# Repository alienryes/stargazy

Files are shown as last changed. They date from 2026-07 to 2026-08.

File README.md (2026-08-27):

# 🌌 Stargazy

A stargazing conditions display for the [Raspberry Pi Touch Display 2](https://www.raspberrypi.com/documentation/accessories/touch-display-2.html). It fetches live [AstroWeather](https://github.com/mawinkler/astroweather) forecast data (on the Pi itself, or from Home Assistant if available) and renders an overnight forecast over a live, data-reactive animated night sky, with no interaction required.

Rendered with Pillow and written straight to the Linux framebuffer (`/dev/fb0`) — no X and no display server.

**There are two builds**, sharing one engine. Pick the one that matches the hardware:

| | [`build5/`](build5/) | [`build10/`](build10/) |
|---|---|---|
| Panel | Touch Display 2, **5 inch** | Touch Display 2, **10.1 inch** |
| Board | Pi 4 | **Pi 5 or CM** — four-lane DSI, a Pi 4 cannot drive it |
| Canvas | 1280×720 landscape, rotated to the panel | 1200×1920 portrait, no rotation |
| Pages | Conditions, targets | Conditions, targets, plus conditional pages for **meteor showers**, **aurora**, **satellite passes** and **the Sun** |
| Status | **Proven in service** | **In service** |

Everything that is not layout (both weather sources, the target reports, the imagery, the animated sky, night mode, touch, the framebuffer) lives in [`core/`](core/) and is shared. The rest of this README describes the 5 inch build unless it says otherwise; substitute `build10/` for `build5/` in the commands to install the other one.

**Highlights**

- Tonight's deep-sky verdict (EXCELLENT → NONE) spelled out in bold display type
- Condition bars: cloudless %, seeing, transparency, calm. A reading below its warning mark is drawn hollow instead of filled. **Cloudless is the inverse of obscuration, not of raw cloud cover**: a sky fully covered by thin cirrus is largely observable and is reported that way
- **A real image of the Moon** for the current hour (true phase, libration and terminator) with constellation and next new/full moon dates
- **A lunar eclipse takes over the moon card** for the day before it starts, with the times clipped to the Moon's own rise and set so the panel cannot name a phase that happens after moonset, and **Earth's shadow drawn across the lunar frame at the real geometry** while it runs
- Footer grouped by type — astronomical (moon dates, dusk/dawn) on the right under the moon; meteorological (lifted index, weather) on the left
- Handles the no-astronomical-darkness case for midsummer at high latitudes
- **Live animated night sky** behind the dashboard: **the actual stars overhead**, plotted from a catalogue at their real positions for the configured location and the moment, plus drifting clouds and meteors from tonight's active showers — all **reactive to the actual conditions**
- **Touch controls** hidden until the screen is tapped: night mode, page rotation, paging through the full deep-sky list, brightness and a true blank that drops the display to 0% CPU

---

## 📸 Display layout

### The 5 inch build

Two pages rotate over the same continuous animated sky. Both shots are real frames from the panel's own Pi 4, rendered from live data:

**Page 1 — tonight's conditions**

![The conditions page: a large GOOD verdict in pale blue-white, four labelled condition bars with percentages, and a photographic waning crescent Moon captioned Waning Crescent in Cancer. Each bar is filled to its value inside a hollow outline, so Seeing at just over half sits visibly short of the other three, which are nearly full. A footer gives tomorrow's forecast, lifted index, temperature, dew point, humidity and wind. A meteor is crossing the sky behind the dashboard.](screenshots/conditions.png)

> **Dusk / Dawn** is used in that footer, not sunrise/sunset: AstroWeather's sun rise/set entities report **civil twilight** bounds (sun 6° below the horizon), ~40 min off the geometric sun crossing. True darkness is tracked separately (`astronomical_night_duration`) and drives the "NO DARK SKY" state.

**Page 2 — tonight's targets**

![The 5 inch targets page: a dusk-to-dawn timeline with the astronomical dark window highlighted; an altitude-versus-bearing plot of the planets, with a line beneath it naming the bodies still below the horizon and the times they rise; and four deep-sky cards headed with the range on show out of a much longer list, each card carrying a real sky photograph, object type, constellation, peak altitude and a bar for the share of the dark hours the object stays up.](screenshots/targets.png)

The page-2 timeline only appears once UpTonight has run, and the page leaves the rotation entirely if it has produced nothing, so an empty page is never shown.

A page that has nothing to show leaves quietly, since that is the ordinary case and a warning would sit on the panel on a perfectly good night. A page whose data source actually **failed** is named instead: the conditions page lists it as unavailable for that refresh, so a silent gap and a broken feed do not look alike. This matters most on the 10.1 inch build, where five conditional pages draw on separate feeds.

**Night mode — the same page after dark**

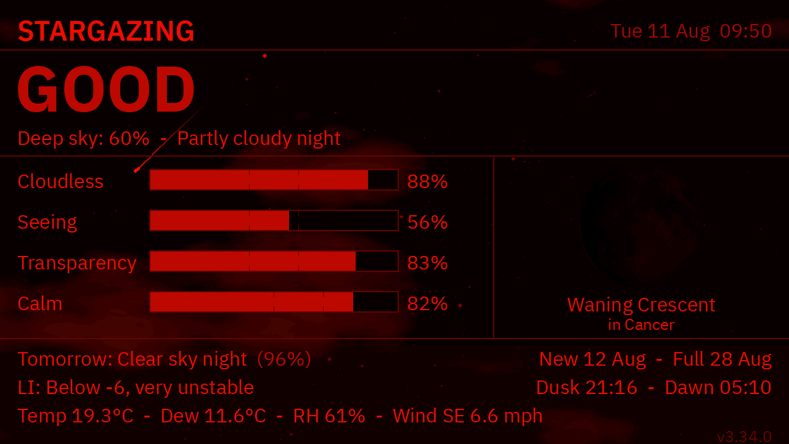
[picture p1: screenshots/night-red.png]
The conditions page in red night mode: the identical layout rendered entirely in shades of red on black, including the photograph of the Moon. The verdict, the condition bars, the percentages and the footer are all still legible, and the bars that fall below their warning marks still read as hollow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


Between real dusk and dawn (not on a clock schedule) the finished frame is put through a red filter, because long wavelengths don't disrupt dark-adapted vision. The whole frame is filtered rather than the palette swapped, which keeps the lunar photograph and the deep-sky cutouts from glowing white.

Because none of the states on the display are encoded by hue, no information is lost. The main verdict is a word, every bar has a number and a length, and a reading below its threshold is hollow rather than a different colour. `night_mode = "dim"` keeps full colour at reduced brightness instead.

### Colour marks real objects; state is neutral

If something on the display is coloured it is a thing that is actually up there — the Moon, a planet, a comet, a photograph of a nebula. If it is a judgement about tonight it is the same neutral blue-white as everything else.

### The 10.1 inch build

Orientation is portrait, 2.5× the pixels at slightly lower density, so the space is used for extra content rather than for scaling. These are real frames captured from the panel's own framebuffer, in service:

**Page 1 — conditions.** The Moon takes the middle band at 600px across; the source frame is 730px, so this is close to native rather than an enlargement. Under it are the numbers that come with the frame and are not used for the 5 inch display — age, distance, apparent diameter, and libration as the direction the near side is tipped.

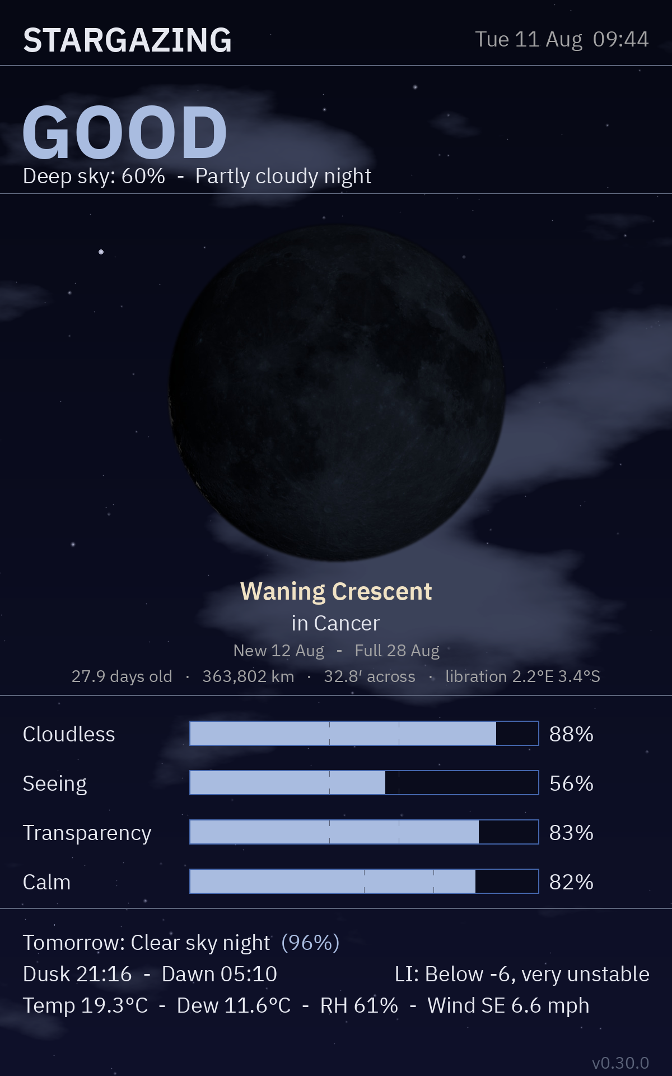
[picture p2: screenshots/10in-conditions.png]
The 10.1 inch conditions page in portrait: a large GOOD verdict, a 600-pixel photograph of a waning crescent Moon captioned Waning Crescent in Cancer with its age, distance, diameter and libration, four condition bars, and a footer of forecast, dusk and dawn times and weather.


**Page 2 — targets.** One altitude-versus-bearing plot carries the planets *and* the deep-sky objects on a full 0–90° axis. The 5 inch build keeps the two apart because it has far less vertical room: UpTonight selects deep-sky targets for high altitude, while the planets stay near the ecliptic and so occupy a lower band, and a short axis holding both compresses whichever band is lower. How far apart those bands sit depends on latitude — from the reference location at 51°N the objects peak around 70–85° and the planets stay below about 35°, but nearer the equator, the ecliptic rides much higher and the two overlap. Every position on the plot is for the single instant named above it.

![The 10.1 inch targets page: a dusk-to-dawn timeline; an altitude-versus-bearing plot carrying the planets alongside the same deep-sky objects as the cards below, each labelled with its bearing; a line naming the bodies still below the horizon with the times they rise; and six deep-sky cards headed with the range on show out of a much longer list, each with a real sky photograph, object type, constellation, peak altitude and where it stands at the plotted instant.](screenshots/10in-targets.png)

**Page 3 — meteors.** Which showers are actually running, from a table of orbital constants indexed by solar longitude, with the rate an observer would count once radiant altitude, cloud and moonlight are accounted for.

A shower is named until its zenithal hourly rate falls to a quarter of the sporadic background's; that background is shown at the foot of the page. Past that threshold it drops off, even though its activity window has not closed; a named row implies something to watch for and when a shower is at a fraction of the background rate it doesn't qualify any more. The windows vary twentyfold in how long they run past maximum, so the cut is made against the rate rather than a number of days. The comparison is made in ZHR rather than in the rates printed on the page, so it does not move with the site's latitude, the radiant's altitude tonight, or the weather. When nothing clears the floor the page leaves the rotation entirely.

The printed rates carry a decimal place below 1/hr. Most nights sit in low single digits and cloud divides them again, so whole numbers at that end of the range have two values and one of them is zero — which would have a named shower reporting that nothing was falling, directly above a sporadic background it is a third of.

![The 10.1 inch meteor page: a header giving the instant the rates are computed for and the current solar longitude, then a row per running shower with its days before or past peak, the radiant's altitude and bearing, a bar and a figure for the rate an observer would count, and its zenithal hourly rate at maximum. Below them a Coming Up list of forthcoming shower peaks with the days to each, and a footer giving the sporadic background rate. Meteors are falling in the sky behind the text, drawn as tapering streaks brightest at the leading end.](screenshots/10in-meteors.png)

---

## ✨ The animated sky

The sky is a live layer composited behind the dashboard each frame (12 fps on a Pi 4 - see the note under Running); the dashboard itself is an RGBA overlay (transparent where the sky should show, opaque content on top). The animation **reflects the conditions** rather than just decorating:

| Condition | Effect |
|---|---|
| Seeing / transparency / calm | Star brightness and twinkle (crisper when clear) |
| Cloud **obscuration** | Fraction of the sky the cloud field obscures, and the stars behind it go out. Derived from the forecast's high/medium/low split rather than its raw cloud fraction. 100% thin cirrus stops far less starlight than 100% stratus, and the raw figure counts them the same. Layers combine as independent transmittances, weighted by `cloudcover_*_weakening`. Falls back to raw cover where the per-layer figures are unavailable |
| Wind speed | How fast the cloud drifts, derived from the wind and a nominal 1500 m cloud base and then time-compressed (`CLOUD_COMPRESSION`, default 8). The honest rate is far too slow to read as motion. Stated as degrees of sky per second, so both panels show the same weather at the same apparent speed despite their different angular scales |
| No astronomical darkness | Sky washes to twilight blue; meteors suppressed |

The moon card shows **a real image of the Moon** (set `display.moon_ring = true` to outline the full disc), fetched hourly from NASA SVS's Dial-a-Moon and cached on disk. It uses actual phase, libration and terminator rather than a drawn approximation. If the API can't be reached the display falls back to drawing the phase geometrically, so it degrades rather than breaks. It deliberately does not reuse an older cached frame: the phase moves about 12° a day, so yesterday's picture would be incorrect, and the correct drawing is better than an attractive but wrong photograph.

**A lunar eclipse replaces those captions** for the 24 hours before it begins, on both builds: the kind of eclipse, the window it can be watched in, and how much of the Moon's diameter enters the umbra. The 10.1 inch build has the room for two further lines and adds the date and an observing note.

**The times are clipped to the Moon's own rise and set, and that is the part that depends on the site.** A lunar eclipse is visible from a whole hemisphere at once, so "is it visible from here" barely filters anything; what is genuinely local is that the Moon can set partway through. At the partial eclipse of 28 August 2026, seen from 51.4°N, the shadow left the Moon at 06:52 with the Moon already below the horizon (it set at 06:24, still deep in the umbra). The card gives the window as ending at moonset and says how much of the eclipse that costs, rather than printing a last contact for something that has gone.

**Earth's shadow is drawn over the lunar frame while the eclipse is running**, because the frame does not carry it: Dial-a-Moon models phase and libration but not eclipses, and reports an obscuration of zero at the maximum of this one. Without the overlay the card would show an ordinary full Moon directly above a caption announcing an eclipse.

**The geometry is computed; the colour is representative.** The shadow's size, position and the curvature of its edge against the limb are real — the umbra is about 2.7 lunar radii across, and it is scaled by the same factor as the disc, so the relation between the two is exact even though the disc itself is drawn far larger than the Moon's true angular size. What is not physical is the brightness: a real umbra is thousands of times fainter than the full Moon, which on a panel in a lit room would simply read as absent, so the shadowed part is drawn as a dim copper (the colour comes from sunlight refracted through Earth's atmosphere, reddened the way a sunset is). The shading is carried by brightness rather than hue, so it survives red night mode — which is the mode the panel is in whenever an eclipse is worth watching.

**The shadow's position is as fresh as the rest of the page**, which is to say it advances a step at each data refresh rather than continuously.

**Only umbral eclipses appear.** A penumbral eclipse is a faint shading that cannot be separated from an ordinary full Moon by eye, and the penumbral contacts of a partial one are no more visible — announcing them would name a time to go out and look at nothing. This is the same test every conditional page here has to pass.

Like the solar eclipse on the 10.1 inch build's Sun page, **it needs no network**: it is computed locally and cached until the event has passed, so it still announces itself with the internet down.

Star and cloud brightness always keep a visible floor, so the sky stays alive even on poor nights.

**The clouds pass behind the moon card, and that is deliberate.** The disc on the dashboard is a *card*, not a view through a window; it is drawn about fifty times the Moon's true angular size (the sky layer runs roughly 21 pixels per degree on the 10.1 inch panel, where the real Moon would be about 11 pixels across) and it sits at a fixed place in the layout rather than where the Moon actually is. Letting cloud drift across it would suggest that the Moon really is there, that large, in that direction. The dashboard describes the sky; only the layer behind it depicts the sky. The Moon's true position is on the targets page, on the alt-az plot with the other potential targets for the night.

### The starfield is the real sky

The stars behind the dashboard are not decoration. They are plotted from the Yale Bright Star Catalogue at their true altitude and azimuth for the configured location and the current moment, recomputed every minute, and they drift in line with the Earth's spin.

**Constellations are recognisable**. This was checked on the panel; on 11 August 2026 at 09:30 the 10.1 inch build had all seven of Orion's main stars in frame, Betelgeuse within two degrees of the view centre, and the belt read at a glance. This was during daylight: Orion is a morning object in August, so the panel was showing a dark sky that could not have been seen out of the window at the time.

**Only displayed down to a `limiting_magnitude`, default 5.0 — not the catalogue's 6.5.** The catalogue's faint end references stars nobody at the reference location would see: measured over the 5 inch field of view it put 1,204 stars on screen, of which 983 were fainter than magnitude 5 and those carried 56% of the drawn area. They buried the sixteen stars that actually made a pattern, and a real sky came out looking random. Raise it for a genuinely dark site. The catalogue ships in the repository, so this needs no network connectivity.

**The panel does not know which way it is facing, so the direction in which it looks is configuration rather than something inferred:**

```toml
[sky]
real_stars = true
camera_azimuth = 180    # degrees: 0 = north, 90 = east, 180 = south
camera_altitude = 45    # degrees above the horizon at the centre of the view
field_of_view = 70      # degrees, vertical (build10 defaults to 90)
```

The default view faces **due south at 45° up**, which is where objects transit and therefore the most useful direction at northern latitudes. Point it wherever the window actually faces, or wherever the view is best. The horizontal field is derived from the panel's aspect ratio so the scale stays even in both directions — which means the landscape 5 inch build sees considerably more sky than the portrait 10.1 inch one at the same vertical setting.

Brightness and star size are mapped for legibility at a distance rather than photometrically: the ordering is faithful, so Sirius still dominates, but the range is compressed; a sky spanning eight magnitudes is drawn across about 1.5, with size carrying the rest. Each panel has its own size table, because the 10.1 inch shows a narrower window of sky magnified over 2.5× the pixels. Set `real_stars = false` for a pseudo-random starfield.

### The meteors follow tonight's real showers

**They are representations, not observations.** A meteor on the panel does not correspond to a meteor in the sky, and nothing on the panel is a live feed. What is real is everything governing their behaviour — when they fall, how often, and which direction they go.

**The cadence** comes from the same computation that fills the 10.1 inch meteor page: which showers are running, how high each radiant sits, and how much of the rate is reduced by cloud and moonlight. So a quiet night in March shows almost nothing and a clear Perseid peak is busy, and if nothing is falling, nothing falls on the display either. The rate is deliberately time-compressed (`meteor_compression`, default 20), because a real three-an-hour would make the animated sky look broken; it does scale what is there but doesn't invent anything.

**The direction** is the true radiant. A meteor is drawn from one of tonight's active showers in proportion to that shower's rate, and travels away from where that shower's radiant actually is in the projected sky, so it converges on a point that agrees with the stars around it. Trails shorten towards the radiant, since a path pointing at the observer would be seen end-on. The radiant can quite often be off the edge of the panel, as the view faces one direction and the shower is in another, so its meteors sweep in near-parallel from that side. Meteors belonging to no shower (the sporadic background, which is most of them on an ordinary night) use an arbitrary direction, because they genuinely have none. Setting `sky.real_stars = false` sets the meteors to arbitrary directions along with the pseudo-random starfield.

Sources for the animated sky: the Yale Bright Star Catalogue (Hoffleit & Warren, 5th revised edition) via VizieR at CDS Strasbourg for the starfield; NASA SVS's Dial-a-Moon, by Ernie Wright, for the lunar frame; the IMO Working List of Visual Meteor Showers for radiants, peaks and zenithal hourly rates, with the activity falloff from Jenniskens (1994). The catalogue and the shower table ship in the repository; only the lunar frame is fetched.

---

### Aurora, when there is any (10.1 inch build)

This page exists **only when aurora is above the configured location's horizon and it is dark enough to see it**. At temperate latitudes that means it may be absent for years at a time; in Iceland or northern Norway it will be a regular fixture. Both are correct, and the frequency difference is real rather than a setting.

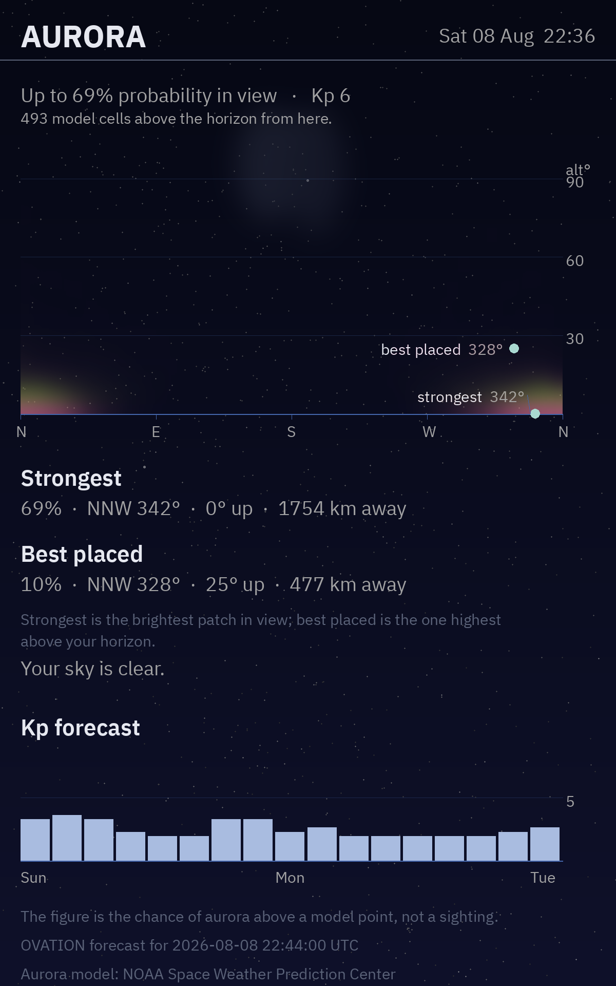
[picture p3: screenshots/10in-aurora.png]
The aurora page during a real storm: 69 percent probability at bearing 342 degrees on the horizon, a second cell 25 degrees up to the north-north-west, a drawn field along the northern horizon shading from yellow-green low down to magenta above, and the three-day Kp forecast.


> **A real storm, 8 August 2026, Kp 6.** The strongest cell was 69% at 1,754 km on the horizon to the north-north-west; the best-placed one 10% at 25° elevation and 477 km. Captured with `--no-night` so the emission-height colours are visible. Between dusk and dawn the panel renders this page in red, which is when it exists. This replaces the injected-storm screenshot the page shipped with, retained as `screenshots/10in-aurora-simulated.png`.

**The query is not "the probability at my latitude".** Aurora emits 100–250 km up, so it is visible far beyond the ground it sits over; from 51°N the horizon reaches past 67°N. Reading only the model cell that contains the configured location can return zero even though a good display is genuinely visible to the north or south. Instead, every model cell within the horizon is searched.

**The direction is not assumed.** The auroral oval passes overhead at high latitudes and lies to the *south* in the southern hemisphere, so the bearing and elevation are computed rather than presumed. The same code answers "north and low" from southern England, "overhead" from Reykjavik and "south" from Tasmania, none of them special-cased.

Two model cells are reported, because they answer different questions and are routinely different: the **strongest**, and the **best placed** — the highest above the horizon. The strongest is often the one grazing the horizon, where the whole thickness of the atmosphere and any terrain at all stand in the way. So reporting that cell alone may send the observer to look at nothing.

**The storm itself is drawn**, not just its extremes: every lit model cell is classified by bearing and elevation and shaded by its probability, so the shape on the plot is the model's own from the observer's position. Opacity *is* the probability (a 60% cell is drawn 60% solid), and the blur only smooths the grid's steps. No structure is added; curtains and rays are not something the model can resolve.

**Colour follows emission height.** The green line is emitted around 100–150 km and the red from 200 km upward, and the Earth hides the lower part first. So the colour is computed from the lowest altitude still above the horizon at each cell's distance. A distant aurora renders red because the red tops are genuinely all that clears the horizon, and one overhead renders green. That is why southern England reports a red glow while Tromsø gets green, and the same code produces both. It is an inference from geometry rather than something OVATION reports, and between dusk and dawn the panel's night mode collapses everything to red luma anyway, so the colour is naturalism and doesn't carry meaning on its own.

The page also carries SWPC's three-day Kp outlook, and says whether the local sky is clear enough to act on any of it. Everything shown is a **probability from a model, roughly 76 minutes ahead of its observation time** — not an observation.

Source: NOAA SWPC's OVATION model. No key, no registration.

---

### Satellite passes (10.1 inch build)

A page that appears **when a bright satellite crosses this sky within the coming day**. Unlike the other conditional pages it is not gated on the sky being dark now, because a pass is an appointment rather than a condition.

![The 10.1 inch satellite page in portrait: a headline naming the next bright pass with its time and how long until it, trailed by a solid line sample keying it to the plot, then a line giving where it rises, how high it climbs and in which direction, and where it sets, and a line giving minutes in view and range at its highest. Below that an altitude-versus-bearing plot on a 0 to 90 degree axis over the compass points, carrying one solid beaded arc for that pass with a round marker part way down its descending limb, and three dashed arcs behind it for the other passes of the same night. Beneath the plot two listings: tonight's passes, each row giving date, time, object, its dash pattern, peak altitude and the bearings it travels between; and the best for the next seven days, whose rows carry no dash sample because they are not plotted. A three-line footer explains the beads, the marker and the faint track, and credits CelesTrak for the elements along with their age. Cloud drifts behind the whole page.](screenshots/10in-satellites.png)

> **A real capture, 18 August 2026**, taken off the panel with the rotation paused on this page. The next pass was still eleven hours away, which is why the page was up in daylight: it is gated on a pass falling within the day, not on the sky being dark now.

**This is the one man-made thing the display will draw into the sky layer.** Everything in that layer claims to be in front of the observer at that bearing and that altitude, and a pass can honour the claim: the object really is there, at that minute. The aurora field and the Moon card are dashboard content precisely because they cannot.

**Visibility is not darkness alone.** The satellite has to be in sunlight while the observer is not, which is why passes belong to twilight rather than the middle of the night, when the object is in the Earth's shadow and there is nothing to see. The gate is civil twilight rather than the astronomical darkness the aurora page waits for, since waiting for full darkness would discard the twilight passes, which are most of the good ones. A pass also has to reach 10° at its highest to be worth announcing, or it spends its whole duration in haze and behind whatever is on the horizon.

**Nothing here predicts a brightness.** Apparent magnitude depends on which face is turned towards the observer, and no keyless source reports the attitude. Range and altitude are given instead, both computed rather than estimated. Which objects are bright enough to qualify at all is CelesTrak's judgement: the page tracks its `visual` group rather than a list kept in this repository, which would decay silently as objects re-enter and new ones launch. Rocket bodies, debris and numbered military payloads are filtered out by name, leaving the named payloads — the two stations, the BlueBirds, and the reliable sun-synchronous set.

**Ranking on height alone was measured to be worse than no ranking.** Across the group a week holds dozens of near-zenith passes, so height saturates and the winner is effectively arbitrary: the page once led with a 1970 ion-engine testbed at three in the morning while an ISS pass the same evening went unmentioned. Objects are sorted into two tiers instead, with height ordering them within a tier.

**The path is why this is a page rather than a line of text.** The headline pass is plotted on the same bearing-by-altitude panorama the other pages use, so the track needs no axes of its own. Beads along it mark minutes, a faint stretch is time spent in the Earth's shadow, and the moving marker shows direction rather than speed. The other passes of the same night are drawn behind it, dimmed, each keyed by its dash pattern to its row in the listing beneath, so an arc and the row describing it cannot disagree. Below the plot are two blocks: tonight's passes, and the best of the next seven days.

The listing reaches a week while the page itself is gated on the coming day, because whether the page exists is a question about acting tonight and the list is a schedule. It stops at a week deliberately: pass times come from orbital elements that age, and quoting a minute a fortnight out would state a precision the elements do not carry. Elements are refreshed twice a day and the display refuses to predict from a set more than three days old, because a stale element set does not produce an obviously wrong answer, it produces a plausible one at the wrong minute. `[satellites] enabled = false` removes the page.

Source: CelesTrak's GP element sets, one grouped request rather than one per object. No key, no registration.

---

### The Sun, while it is up (10.1 inch build)

Every other conditional page here exists only after dark, because aurora and meteors are conditions of the night sky. This page inverts that: it appears **whenever the Sun is above the horizon**, and fills the hours when the rest of the panel has less to say.

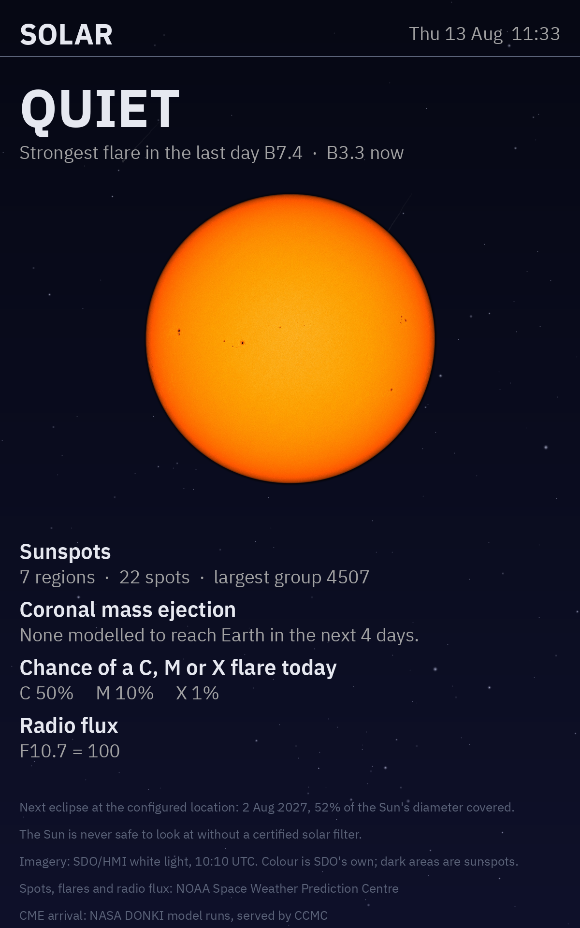
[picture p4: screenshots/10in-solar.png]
The solar page on a quiet day: the word QUIET over the day's strongest flare, rows for sunspots, coronal mass ejections, flare odds and radio flux, and below them a photograph of the Sun's disc in white light with individual sunspots visible as small dark marks.


> **An ordinary quiet day, 13 August 2026** — captured off the panel. Seven spot regions, nothing above a B-class flare, and no CME modelled to arrive.

It is also the only page here that is **always present rather than gated on something happening**. That is a deliberate departure from the rule the other pages follow, because the Sun is always there: a quiet Sun is still a fact about today, not just an empty page.

**The disc is a photograph.** SDO's HMI continuum frame; the white-light view, which is the one with the sunspots actually in it. It is composited the same way the Moon card composites its Dial-a-Moon frame, on the same black field with the same circular mask. The mask is doing real work here: it removes the caption strip SDO prints along the bottom of every frame. What the frame resolves is **individual spots** rather than the groups they belong to: labelling the dark blobs gives 11–21 of them against SWPC's 22 spots in 7 regions on the same day, so the credit names spots and the sunspot row carries both counts. The colour is SDO's own, a table applied to continuum intensity: from space the Sun is white, and the page states that the colour is applied rather than observed. All of that sits in the footnotes as `Imagery: …`, with the other attributions, rather than as a caption under the disc.

The imagery replaced a drawn disc and fixed the issues it brought with it. The drawing plotted each group from SWPC's regional report and overlaying those computed positions on an SDO frame showed **every mark sitting east of its real spot by about the same amount** — because the report is a *daily* snapshot while solar rotation carries a group roughly 13.2° a day, up to 110 px at this scale by the time the next one is issued. The projection was correct; its input was stale, and only a photograph could have shown that. A frame has no such lag: it shows the spots where they were at its own timestamp, which is what the page displays.

The drawn disc survives as the fallback for when SDO cannot be reached — orthographic, tilted by the season (the Sun's axis leans up to 7.25° either way through the year, so the equator bows off centre and the disc reads as a sphere), far-side groups dropped rather than folded onto the wrong limb, and solar west to the right as in every published solar image. In that state the marks are enlarged to be visible and the caption says the positions are as last reported rather than as they are in the present.

**An eclipse gets top billing** when one is due within a day, with a countdown. It is stated as a single line at the foot however far off it is otherwise; the rarest thing this panel shows is worth knowing about in advance. From southern England expect roughly one visible partial a year and none at all in some years; the next is 2 August 2027.

**Magnitude and obscuration are given separately and named separately.** Magnitude is the fraction of the Sun's *diameter* covered, obscuration the fraction of its *area*. They're not the same number: at a deep partial they differ by ten points. The page never prints one under the other's label.

**The eclipse needs no network at all.** It is computed locally from the Sun's and Moon's apparent discs, seen from the configured location so that lunar parallax is included. That makes it the one thing this display can still announce with the internet down.

**Nothing on the page is phrased as an instruction or invitation to look at the Sun without protection**, and the filter warning follows what it qualifies: it sits beside the coverage figures while an eclipse holds the top of the page, and in the footnotes the rest of the time, alongside the next eclipse line.

Sources: NOAA SWPC for spots, flares and radio flux; NASA's DONKI model runs served by CCMC for a coronal mass ejection's predicted arrival and Kp; NASA SDO/HMI for the disc. All keyless, none requiring registration.

## 👆 Touch controls

Since the panel is a touchscreen, there are touch controls. The display reads them directly from `/dev/input/eventN`, so neither X nor Wayland is required.

No controls are drawn until the screen is touched. **The first tap only reveals a control strip** along the bottom, which will disappear after six seconds; a second tap presses a button. That way the ambient display stays uncluttered and brushing past the panel in the dark can't affect anything.

The buttons carry glyphs rather than words, drawn from primitives rather than shipped as an icon font. Each shows what pressing it will **do**, the way a play triangle does — the moon means "press for night", not "it is night".

| Button | Glyph | What it does |
|---|---|---|
| Night / Day | crescent moon / rayed sun | Turns the red night filter on or off, immediately, whatever the hour |
| Pause / Resume | two bars / triangle | Holds the current page instead of rotating |
| Next | chevron | Jumps to the next page straight away |
| Dimmer / Brighter | hollow sun with − / + | Backlight, via `/sys/class/backlight`. Never goes below the lowest visible step |
| Blank | screen with a slash | Backlight off and compositing stopped. The display drops to **0% CPU** until it is touched again. |
| More | three dots | *Targets page only.* Steps to the next screenful of deep-sky objects, and wraps at the end |

The Day sun is **solid** and the brightness suns are **hollow**, which is the same distinction doing real work: both can be on the strip at once, since Day appears whenever the filter is on.

**State is coded in luma, not hue** — fill against outline, solid against hollow — because the night filter puts Rec.709 luma on the red channel and destroys hue outright. A colour code would read correctly by day and collapse into an arbitrary brightness code after dusk, which is the whole time anyone is out there touching the panel.

The moon is the single exception, and it is a provable one. It is drawn only when the filter is off, so it is never transformed, and it is painted in the colour white *becomes* under the filter — the button previews the change it makes. The sun is its mirror, shown only while the filter is on, so it carries no colour and does not try to: at night the whole panel is already red, and previewing "day" would restate what fills the view.

**More** exists because the deep-sky list is far longer than one screenful. UpTonight commonly passes forty objects on a dark night, against six cards on the 10.1 inch panel and four on the 5 inch, and the heading has always said so — `DEEP SKY (1–6 of 40)`. Pressing **More** reaches the rest, six or four at a time; on the 10.1 inch build the altitude-versus-bearing plot follows, so the plot and the cards always describe the same objects.

Every screenful is drawn in advance on the data thread, along with the sky photograph for each object, because stepping between them happens on the render loop where a fetch is too expensive. The page rotation also holds while the control strip is showing, so a page cannot turn mid-press.

A night mode picked by hand lapses the next time the sky crosses dusk or dawn: it is a change of state for that night, not a second schedule competing with the automatic one. Nothing else in the touch controls is persisted. `config.toml` is restored on restart, so the display always comes back to a known state.

This functionality requires `display.mode = "animated"`, and an account in the `input` and `video` groups (`setup.sh` arranges both). Set `touch.enabled = false` to turn the touch controls off.

---

## 🛠️ Requirements

**Hardware** — the whole build, and roughly what it costs:

| Item | Qty | Notes |
|---|---|---|
| Raspberry Pi 4 Model B (2GB is plenty) | 1 | What this is built and proven on. See the Pi 5 note below |
| Raspberry Pi Touch Display 2, **5 inch** | 1 | 720×1280 DSI. Ships with a Pi 4 DSI cable |
| Official Raspberry Pi USB-C PSU (5.1V/3A) | 1 | The printed stand is sized so this one's stiff cable clears the desk |
| microSD card, 16GB+ | 1 | Raspberry Pi OS Lite 64-bit |
| 3D-printed case and stands | 1 set | Optional — see [`case/`](case/README.md). ~150g of PETG |
| M2.5 screws and standoffs | 1 set | Only for the case; full list in [`case/README.md`](case/README.md) |

No soldering, no HAT, no GPIO wiring. The display is DSI and the case is all screws and standoffs. If a 5v GPIO pin is required then the 0 v pin of the display connector can be shifted to the middle pin and the connector moved right by one pin. This frees up Pin 2. Normally the connector connects via Pin 2 and Pin 6, which blocks pin 4.

> **Using a Pi 5 for the 5 inch build gives no advantage.** It needs a Display Adapter Cable for Pi 5 (22-way → 15-way, the one marked `DISPLAY`), and there is no performance reason to move: the render loop is single-threaded and uses about one core of four. The case *does* have a printable Pi 5 variant.
>
> The framebuffer format differs between the two panels and is **detected at runtime**, so neither build needs configuring for it: the 5 inch reports 16bpp RGB565, the 10.1 inch on a Pi 5 reports 32bpp XRGB8888. To see what a board presents:
> ```bash
> cat /sys/class/graphics/fb0/bits_per_pixel /sys/class/graphics/fb0/virtual_size
> ```
> A padded framebuffer (one whose `stride` exceeds width × bytes-per-pixel) is not supported, and is refused at startup rather than rendered as a diagonal smear. Neither panel pads.

**For the 10.1 inch build**, the table changes: a **Raspberry Pi 5** (its DSI is four-lane, which the panel requires), the **10.1 inch** Touch Display 2, a 27W USB-C PSU, and the official **Pi 5 Active Cooler**, which is required rather than optional on a continuous render loop.

**The 10.1 inch build deliberately has no case, and doesn't need one.** The Pi bolts to the standard 58 × 49 mm hole pattern in the middle of the panel's back, which mounts it properly on its own — unlike the 5 inch, where the case and the Pi share one screw chain. Leaving the board open also suits the active cooler, which needs free air rather than a grille. The panel is 247 mm tall in its native portrait with the Pi centred, so there is roughly 80–95 mm below the board for the display ribbon and the power cable to turn and drop; the 5 inch needs a stand partly because rotating it to landscape leaves only about 18 mm there. A stand is still wanted for the 10.1 inch, but that is a question of how it sits on a desk, not of enclosing anything.

**Software**
- Raspberry Pi OS Lite 64-bit (Trixie / Bookworm), headless (`multi-user.target`)
- Python 3.11+
- **No Home Assistant required.** Weather comes from [pyastroweatherio](https://github.com/mawinkler/pyastroweatherio), the library the Home Assistant [AstroWeather](https://github.com/mawinkler/astroweather) integration itself wraps, talking straight to MET Norway and Open-Meteo. If Home Assistant is available with that integration, then set `weather.source = "homeassistant"` and the display reads its sensors instead.
- **An internet connection**, but nothing else on the local network. The 5 inch build uses three public services: the weather above, NASA SVS for the lunar image, and CDS Strasbourg for the deep-sky cutouts. The 10.1 inch build adds four more for its conditional pages: NOAA SWPC for aurora and space weather, NASA's DONKI runs served by CCMC for CME arrival, NASA SDO for the solar disc, and CelesTrak for the satellite elements. All are keyless and none require registration. No broker, no container, no local servers. Each one degrades on its own if it's unreachable. The moon falls back to a drawn phase, the cutouts to drawn glyphs, and cached weather keeps the dashboard up.

---

## 🚀 Setup

### 1. Pi one-time setup

The 5 inch Touch Display 2 is auto-detected over DSI and needs no device-tree overlay. **The 10.1 inch is not**: `display_auto_detect=1` is firmware-side probing, so firmware older than the panel does not recognise it, and the symptom is no output *and* no DSI connector at all in `/sys/class/drm`. For that panel, add the overlay to `/boot/firmware/config.txt` and reboot before running setup:

```
dtoverlay=vc4-kms-dsi-ili79600-10-1inch
```

Append `,dsi0` only if the ribbon is in CAM/DISP 0. The overlay defaults to DSI1, which is CAM/DISP 1. Then run the setup script:

```bash
# Copy the build's setup.sh to the Pi, then:
sudo bash setup.sh          # or: sudo bash setup.sh <username>
sudo reboot                 # required: setup.sh adds fbcon=map:2 to the kernel cmdline
```

With no argument it sets everything up for the account that invoked `sudo`, which is almost always what is required. Pass a username only if installing on behalf of a different account.

`setup.sh`:
- installs `fonts-ibm-plex` (the display's typeface), `fonts-dejavu-core` (fallback), `python3-pil`, `python3-numpy`, `python3-requests`, `python3-pip`, `python3-venv`
- builds the display's virtualenv, reusing apt's Pillow and NumPy rather than rebuilding them
- adds the user to the `video` group (framebuffer + backlight) and `input` group (touchscreen)
- adds `fbcon=map:2` to `/boot/firmware/cmdline.txt` so the text console never draws over the display
- installs a deliberately narrow sudoers rule for the deploy script — see the security note below

### 2. Create config

```bash
cp build5/config.example.toml build5/config.toml
```

Set the desired observing location in `[location]`; that is the only thing that MUST be edited (unless the location is Greenwich, London, UK, which is the default). The default `weather.source = "direct"` fetches the forecast on the Pi itself and needs no credentials at all:

```toml
[weather]
source = "direct"

[location]
latitude = 51.4779
longitude = -0.0015
elevation = 47
timezone = "Europe/London"

[display]
# mode = "animated"     # or "static" (redraw only when the data changes)
# fps = 12
# data_refresh_min = 15
```

**Every setting with a code default ships commented out, holding that default.** Uncommenting one pins it: the value then survives upgrades, and a later change to the default stops reaching that machine. The file is therefore a list of what can be changed rather than a set of choices already made, and a working install can consist of `[location]` alone.

That distinction is not cosmetic. The Open-Meteo model was pinned in code to a coarse global grid until 2026-08-11, when it reported 60% high cloud over a photographed clear sky; had the panels also pinned `forecast_model` in their own config, correcting the default would have deployed and silently done nothing.

**Night mode** (`night_mode = "off" | "dim" | "red"`) applies between real dusk and dawn rather than on a clock schedule, because the point is to stop the panel ruining dark adaptation and that starts when the dark sky does. `"dim"` keeps the colours at `night_dim`% brightness; `"red"` goes monochrome red because long wavelengths leave low-light vision alone. Nothing is lost by going red. No reading is carried by colour alone, so the verdict word, the numbers and the bar lengths all still say what they said. It applies to the finished frame, so it covers the animated sky and the sky photographs too.

**Backlight** (`brightness`, a percentage of the panel's maximum, default 100) is applied at startup. It is set rather than left alone because the backlight is the one setting the hardware keeps across a restart: left alone, the panel comes back at whatever the Dimmer and Brighter buttons were last pressed to, and after a reboot at the driver's own value — 4 of 31 on both panels, which is dim enough to read as a fault. Everything else already returns to this file on restart; this makes the backlight do the same.

To read from Home Assistant instead, set `source = "homeassistant"` and add an `[ha]` section with the HA URL and a long-lived access token (HA → Profile → Security → Long-Lived Access Tokens).

Both sources are the same underlying model, so they agree. `display.py --compare` fetches from each back to back and prints a per-value diff if local confirmation is required.

### 3. Deploy

From Windows:

```powershell
.\build5\deploy.ps1 -User <pi-username> -PiHost <hostname-or-ip>
```

Both default to the reference build's values (username `operations` and hostname `stargazy5.local`; the 10.1 inch build's script defaults to `stargazy10.local`), so `.\build5\deploy.ps1` alone works once the local ones match. Otherwise pass them. Unlike `setup.sh`, this runs on a PC and talks to the Pi over SSH, so it cannot infer the remote account name. The host is resolved by mDNS, which works on either the wired or the wireless interface; use an explicit address if mDNS is unavailable.

This copies the files, installs the Python dependencies, stages the systemd units, and restarts the always-on animated display. **The very first deploy (and any later one that changes a unit file) will print one extra command to run**. Installing a systemd unit is done under interactive sudo on the Pi, not automatically.

### A note on security

- **The NOPASSWD sudoers rules cover exactly two commands**: restarting the display service and kicking a first UpTonight run. In particular the deploy account **cannot** install unit files unattended. A unit executes as root, so `build5/systemd/install-units.sh` asks for a password instead. If these rules are widened for convenience, understand that root is being handed to anything that ever compromised the deploy account.
- **Check for `/etc/sudoers.d/90-cloud-init-users`.** A Pi provisioned with Raspberry Pi Imager gets its first user `NOPASSWD:ALL` from cloud-init, which silently defeats the scoped rules above. `sudo -l` will show it. If the account has a usable password (`passwd -S <user>` says `P` — confirm this first, or lose easy root), remove that file and sudo goes back to asking.
- **`deploy.ps1` uses `StrictHostKeyChecking=accept-new`**: first contact trusts the key it sees, after which a changed host key aborts the deploy. If the Pi is reflashed, clear the stale key with `ssh-keygen -R stargazy5.local`.
- `config.toml` is deployed with mode 600, since it can carry a Home Assistant token.
- Python dependencies install **unpinned** (current Pi OS ships Python versions the upstream pins predate). That is a supply-chain trade-off: current wheels are used, not vetted ones. Pin them if that suits the threat model. The riskiest parsers (Pillow, requests, urllib3, NumPy) deliberately come from **apt**, not pip, so Debian's security team patches them; keep that working by running `apt upgrade` occasionally or installing `unattended-upgrades`.
- **Both services run sandboxed** (`NoNewPrivileges`, `ProtectSystem=full` and friends): they parse data fetched from the internet, so the units assume compromise and bound it. Code inside the service cannot invoke sudo at all, whatever the sudoers file says. The unit comments record which protections are deliberately absent and why.
- **`sudo bash harden-pi.sh` does the last two**, and neither is completed by `setup.sh`. They change the machine logon mode, which an application installer should not affect. It switches SSH to key-only (once passwordless sudo is off, the account password is the box's root gate and shouldn't be guessable over the network) and installs `unattended-upgrades`. It refuses to run unless the key is already installed, validates the config, rolls back on failure, and reloads rather than restarts sshd so it cannot strand the access mid-session. **Afterwards root needs the key *and* the password. On a Pi with no keyboard, losing both means pulling the SD card.**

---

## 🖥️ Running & preview

The always-on `stargazy.service` runs `display.py` as a daemon. For manual runs and development:

```bash
python3 display.py            # daemon (mode from config; default animated)
python3 display.py --once     # render one frame to the panel and exit
python3 display.py --save preview.png   # save a single composited frame (no panel needed)
python3 display.py --demo     # force a vivid clear-sky animation, ignoring the weather
python3 display.py --compare  # fetch from both weather sources and diff them
```

`--demo` is handy for checking the vivid end of the range without waiting for a clear night.

`--save` renders the draw path again, so it shows what the code *would* produce. To capture what the panel is **actually showing** (the page the rotation is on, the control strip, the live night filter) read the framebuffer instead:

It reads `/dev/fb0`, so it runs **on the Pi**, where `deploy.ps1` puts it beside `display.py`:

```bash
cd ~/stargazy
.venv/bin/python grab_panel.py --rotate 270 --out panel.png   # 5 inch
.venv/bin/python grab_panel.py --rotate 180 --out panel.png   # 10.1 inch
```

The rotation differs because the framebuffer holds the image in the panel's orientation rather than a readable one, and neither value can be detected from the framebuffer itself. Geometry and colour depth are read from the device. Reading `/dev/fb0` needs membership of the `video` group, which `setup.sh` arranges.

---

## 🧰 Case

A free 3D-printable case for the 5 inch Touch Display 2 + Pi 4 lives in [`case/`](case/README.md) — four parametric CadQuery parts (shell, Pi clamshell, twin bolt-on stands at a 20° lean, optional 40 mm fan). A Pi 5 variant of the two clamshell parts is also generated, built and fitted, though its display ribbon routes differently and needs an adapter cable. It's a **CC BY remix of [RonnyS's Touch Display 2 case](https://www.printables.com/model/1377047-raspberry-pi-touch-display-2-case)**, which targets the 7" panel; this one is re-drawn for the 5 inch. See [`case/README.md`](case/README.md) for print settings, hardware and assembly.

**This is for the 5 inch build only.** The 10.1 inch panel mounts and cools its Pi perfectly well with the board left open — see the note under Requirements.

For the 10.1 inch panel there is a **stand** instead, in [`stand10/`](stand10/README.md): one printed part and two M2.5 screws, holding the panel at a 10° lean with the Pi left open on its back, with two moulded-in collars carrying the power lead down to the desk. It is **GPL-3.0, not CC BY** — nothing in it derives from RonnyS's case, since the 10.1 inch panel decouples its enclosure brackets from the Pi's own mounting pattern and none of the 5 inch design carries over. Printed and in use. Note that the panel mounts 180° from the way it arrives, which is the only orientation the stand fits — see [`stand10/README.md`](stand10/README.md).

The project originally ran on a **Pimoroni Inky Impression 4"** with a bespoke stand (CadQuery frame + riser + WS2812B LED bezel ring). After moving to the self-lit Touch Display 2 that design was retired and archived, with its full history, to a separate private repository.

---

## 🔧 Troubleshooting

| Symptom | Fix |
|---|---|
| Blank panel, or console/login text over the dashboard | The text console is still bound to `/dev/fb0`. Ensure `fbcon=map:2` is in `/boot/firmware/cmdline.txt` and reboot; `fbcon-detach.service` also unbinds it at start |
| Dark panel while the service is healthy and logging normally | The display was never woken: `fbcon=map:2` means no console performs a modeset, and a Pi 5 with `disable_fw_kms_setup=1` has no firmware-set mode either, so the CRTC stays off while frames render into a buffer nobody scans out. The daemon now issues an unblank when it opens the framebuffer, so this should not recur. Confirm with `cat /sys/class/drm/card*-DSI-*/enabled` (want `enabled`) and `cat /sys/class/backlight/*/bl_power` (want `0`, not `4`) |
| `PermissionError` writing `/dev/fb0` | The user isn't in the `video` group — rerun `setup.sh`, or `sudo adduser <user> video` and re-login |
| Sky looks static / no visible animation | Heavy cloud legitimately calms the sky. Confirm with `python3 display.py --demo`; check the computed mood with `python3 -c "import tomllib,display; c=tomllib.load(open('config.toml','rb')); print(display.sky_params(display.make_fetcher(c)()))"` |
| Dashboard upside down / mirrored | Flip `ROTATE` in `display.py` between `Image.ROTATE_90` and `Image.ROTATE_270` |
| `ModuleNotFoundError: numpy` | `sudo apt install python3-numpy` (or rerun `setup.sh`) |
| Tapping the panel does nothing | The log will say `No touchscreen found` if the account isn't in the `input` group — rerun `setup.sh`, or `sudo adduser <user> input` and reboot. Also check `touch.enabled` is true and `display.mode` is `animated`; touch is not wired into static mode |
| Taps land a quarter-turn away from a finger | The touch mapping follows `ROTATE`, so if that is flipped, flip it here too. Check it directly with `python3 touch.py`, which prints raw and mapped coordinates for each tap |
| A button fires when the tap was only meant to wake the strip | The first tap only reveals it. If the strip was already up (it stays for `touch.strip_seconds`), the tap counts as a press; raise or lower that value to suit |
| Drawn moon instead of a photograph | The Dial-a-Moon fetch failed. The log says why. It will not substitute an older cached frame, because the phase moves ~12°/day and yesterday's picture would be wrong |
| `KeyError: 'ha'` in config | Only applies with `weather.source = "homeassistant"`: `config.toml` is missing the `[ha]` section header |
| 401 Unauthorized from HA | Likewise — the token in `config.toml` is wrong or expired |
| The Pi's hostname reverts, days or weeks after being changed | cloud-init owns it on an Imager-provisioned Pi and reapplies it at boot. `sudo bash rename-host.sh <newname>` sets it and disarms that; only a reboot proves it held |
| After a rename, `/etc/hosts` keeps the old name as an alias | cloud-init caches its datasource per instance-id, so correcting `/boot/firmware/user-data` alone has no effect. `sudo bash disable-cloud-init.sh`, then reboot; afterwards `stat -c %y /etc/hosts` must predate `uptime -s` |

**Check logs / CPU:**

```bash
journalctl -u stargazy -f
systemctl status stargazy
```

**The frame rate is a maximum and is not guaranteed**, and the default of 12fps is what both panels hold with room to spare. Measured in red on the live daemons over 150 seconds with no data refresh in the window, the 5 inch draws at about **45% of one core** on a Pi 4 and the 10.1 inch at about **53%** on a Pi 5. Raising `fps` costs CPU in proportion; lowering it reduces CPU. Reproduce either figure with `tools/measure_cpu.py`.

**Daylight is the binding case, not darkness**, which reverses how this build spent most of its life and is worth knowing before tuning `fps` against a night-time reading. The red night transform used to be the expensive mode, having been the one step with no C implementation behind it; it now takes its luma from PIL's matrix convert, and the 16bpp pack takes a lookup table rather than a shift per channel. Both changes favour red, so the daylight path is now the slower of the two.

### Optional: a 32-bit framebuffer on the Pi 4

On a Pi 4 the DSI panel comes up at **16bpp** (RGB565), because that is what the vc4 KMS framebuffer emulation provides. On a Pi 5 the DSI panel is driven by a different driver and already presents 32bpp. Nothing needs configuring for either. The depth is read from the device at startup and the pixel packing follows it.

16bpp can be overridden. Adding this to `/boot/firmware/cmdline.txt` (on the single existing line, space-separated) and rebooting gives 32bpp:

```
video=DSI-1:720x1280-32@60
```

**The connector name differs by board.** It is `DSI-1` on a Pi 4 and `DSI-2` on a Pi 5; `ls /sys/class/drm` gives the right one. The resolution and refresh are required, as the bit-depth suffix alone is ignored. Confirm the result with `cat /sys/class/graphics/fb0/bits_per_pixel`.

**What it buys.** Red night mode packs luma into the five red bits at 16bpp — **32 levels for the whole image**. At 32bpp it is 256. The twilight gradient and the cloud field's soft edges are both smooth ramps drawn almost entirely in one channel after dark, so that is where banding shows if it shows anywhere.

**What it costs.** Measured on a Pi 4, packing one frame:

| night mode | 16bpp | 32bpp |
|---|---|---|
| off | 29.3 ms | **12.2 ms** |
| red | **36.6 ms** | 44.4 ms |

Faster in daylight and slower after dark, which is the wrong way round for a display that runs red from dusk to dawn. The frame still fits inside the 12 fps budget either way, with less margin. Framebuffer memory and write bandwidth double.

Worth it for colour on a panel that is looked at closely; not worth it for speed.

---

## 📁 File structure

There are two builds, differing in panel and board. They share one engine in
`core/`; each build folder holds only what is specific to its hardware — layout,
config, systemd units and deploy script. A build folder plus `core/` is
everything that gets installed on a Pi.

```
core/                   Shared engine: weather sources, target reports, imagery,
                        animated sky, night filter, framebuffer, touch controls
build5/                 5 inch Touch Display 2 on a Pi 4 (720x1280) - the reference build
  display.py              Entry point and 1280x720 layout
  touch.py                Touchscreen reader (evdev; run alone to check mapping)
  config.toml             Local config (gitignored)
  config.example.toml     Template ([weather] + [location] + [display] + [touch])
  deploy.ps1              Windows → Pi deploy script
  setup.sh                One-time Pi setup (run with sudo)
  systemd/
    stargazy.service            Always-on animated display daemon
    fbcon-detach.service        Frees /dev/fb0 from the text console
    install-units.sh            Installs the units - interactive sudo, by design
build10/                10.1 inch Touch Display 2 on a Pi 5 (1200x1920) - portrait,
                        adds a meteor shower PAGE, an aurora page, a satellite
                        pass page and a solar page. Both builds fly real
                        meteors in the sky itself
screenshots/            README images, regenerated with display.py --save
tools/                  Development checks and utilities
  grab_panel.py           Capture what the panel is actually showing, off /dev/fb0
  check_fb_paths.py       Prove the framebuffer fast paths emit the shipped bytes
  check_ranking.py        Deep-sky ordering, incl. UpTonight's 0.0 magnitude
  check_paging.py         Deep-sky card paging arithmetic, both card counts
harden-pi.sh            Optional: key-only SSH + automatic security updates
rename-host.sh          Optional: rename the Pi so the change survives a reboot
disable-cloud-init.sh   Optional: stop cloud-init reapplying its provisioning
case/
  README.md               Print settings, hardware, assembly
  shell.py                Display shell (front frame + back plate)
  pi_models.py            Measured Pi 4 / Pi 5 connector tables
  case_bottom.py          Pi clamshell base (bay, walls, port sill, lid spigots)
  case_top.py             Ventilated lid (ports, fan grille + mounting)
  stand.py                Bolt-on desk stand - print 2
stand10/                Desk stand for the 10.1 inch panel - one part, no case needed
  README.md               Print settings, panel orientation, assembly
  stand10.py              The stand, incl. the power-lead collars
  check_stand10.py        Fit, clearance and overhang checks on the exported STL
```

---

## 💬 Feedback and contributions

Bug reports, questions and build photos are all welcome via [Issues](https://github.com/alienryes/stargazy/issues).

One area where reports are especially useful, because it cannot be verified here:

- **Other latitudes.** The reference build sits at 51°N. The targets page derives its altitude axis from the configured latitude (the highest an ecliptic body can reach, plus the Moon's inclination and a little headroom) so it should not need adjusting anywhere, and reports that it does are useful. The axis also opens beyond that figure for a comet placed higher, comets not being tied to the ecliptic.

---

## 🙏 Acknowledgements

This project is a thin dashboard over other people's hard work.

- **[AstroWeather](https://github.com/mawinkler/astroweather) and [pyastroweatherio](https://github.com/mawinkler/pyastroweatherio)** by Markus Winkler (MIT). The seeing, transparency, calm and deep-sky figures are its model, not a reimplementation of it. The display calls the same library the Home Assistant integration wraps.
- **[UpTonight](https://github.com/mawinkler/uptonight)**, also by Markus Winkler, computes the target lists on the Pi.
- **Weather data** from [MET Norway](https://www.met.no/) and [Open-Meteo](https://open-meteo.com/), via the above.
- **The star catalogue** behind the real sky in both builds is the **Yale Bright Star Catalogue** (Hoffleit & Warren, 5th revised edition), obtained from **VizieR at CDS, Strasbourg Observatory, France** (catalogue V/50) and trimmed to magnitude 6.5 — of which the display draws down to `limiting_magnitude`. It ships in the repository as `core/data/stars.tsv`, so the display needs no network to draw the sky.
- **Sky imagery** from the [`hips2fits` service](https://alasky.cds.unistra.fr/hips-image-services/hips2fits) at **CDS, Strasbourg Observatory, France**, rendering the **DSS2 colour** HiPS survey. The Digitized Sky Survey was produced at the Space Telescope Science Institute under U.S. Government grant NAG W-2166, from photographic data of the Oschin Schmidt Telescope on Palomar Mountain and the UK Schmidt Telescope.
- **Lunar imagery** from **[Dial-a-Moon](https://svs.gsfc.nasa.gov/4442)**, by **Ernie Wright** at **NASA's Scientific Visualization Studio**, rendered from Lunar Reconnaissance Orbiter data. SVS content is public domain. Each frame shows the Moon's real phase, libration and terminator for that hour. The display is compositing an actual render, not drawing an approximation.
- **Aurora forecasts** from the **[NOAA Space Weather Prediction Center](https://www.swpc.noaa.gov/)**: the **OVATION** auroral precipitation model, which gives the probability of aurora above each point of a global grid, and the **planetary K-index** — both the one-minute series and the three-day outlook. SWPC products are U.S. Government works and in the public domain, so this credit is courtesy rather than obligation. The meteorological aurora model is theirs; what this display adds is the horizon geometry that turns it into an answer for one location. The `[aurora]` page needs no key and no registration.
- **Satellite orbital elements** from **[CelesTrak](https://celestrak.org/)**, as GP element sets, keyless and needing no registration. The satellite page tracks CelesTrak's **`visual`** group, which is the set of objects bright enough to be seen without a telescope, so which objects qualify is CelesTrak's judgement rather than a list kept here. Elements age, so the cache expires rather than falling back indefinitely, and the page credits the set's age beside the passes. Brightness itself is not predicted.
- **The case** is a remix of **"Raspberry Pi Touch Display 2 Case" by RonnyS** ([Printables 1377047](https://www.printables.com/model/1377047-raspberry-pi-touch-display-2-case)), used under CC BY.

## 📄 Licence

**GPL-3.0** — see [LICENSE](LICENSE). Chosen to match [pilomar](https://github.com/Short-bus/pilomar), the Pi miniature-observatory project by Short-bus that this display was inspired by.

**Except `case/`**, which is **CC BY** rather than GPL, because it is a remix of RonnyS's CC-BY model and that licence carries forward. Credit RonnyS and alienryes (`@alienryes_42883` on Printables) if remixed further.

`stand10/` is **GPL-3.0** like the rest of the repository. It is the 10.1 inch panel's stand and is original work, not a remix, so the CC BY attribution requirement does not reach it.

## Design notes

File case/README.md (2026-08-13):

# Case — Raspberry Pi Touch Display 2 (5") + Raspberry Pi 4 or Pi 5

A 3D-printable desk case for the **5-inch** Raspberry Pi Touch Display 2 with a
Raspberry Pi 4 or Pi 5 mounted behind it, used landscape. Four printed parts, an
easel stand at a 20° lean, and an optional 40 mm fan.

The two boards share an outline and a mounting pattern, so only the port
openings differ. Print the files for the chosen board — see
[Choosing the board variant](#choosing-the-board-variant), and read it before
committing to a Pi 5: its display ribbon routing is genuinely different and
needs a part the panel does not come with.

## Credits and licence

This is a **remix of "Raspberry Pi Touch Display 2 Case" by RonnyS** —
<https://www.printables.com/model/1377047-raspberry-pi-touch-display-2-case> —
used under **CC BY**. The original targets the **7-inch** panel (its shell
pocket is 187 × 118 mm, matching the 7-inch outline of 189.32 × 120.24 mm); the
5-inch panel is 91.46 × 143.4 mm, so none of the original parts fit it. The
architecture is RonnyS's — shallow shell, bolt-on Pi clamshell, swappable
stand, optional fan — re-drawn parametrically in CadQuery at 5-inch scale.

This remix is released under **CC BY** as well. Credit RonnyS and alienryes
(`@alienryes_42883` on Printables).

The Raspberry Pi board models shown in the assembly diagrams are by
**Pyro_Industries** — <https://www.printables.com/model/727545-raspberry-pi-4>
and <https://www.printables.com/model/727155-raspberry-pi-5>, CC0. They are used
for illustration and for measuring connector positions, and are not
redistributed here.

Differences from the original, beyond scale:

- **No lid towers and no heat-set inserts.** The original bolts its lid to four
  M3-insert towers on the case-bottom, which forces a wider lid and a second
  screw chain. Here the lid screws into M2.5 male-female standoffs sitting on
  the Pi's own mounting holes, so one chain runs the whole stack and the lid
  continues the case-bottom's wall profile instead of straddling it.
- **The lid is located by four spigots, not by its screws.** The original's lid
  bolts into towers rising from its own plate — a short, stiff chain that needs
  no help. Ours bolts into standoffs stacked on the Pi, which is stacked on
  extenders, so the screws alone let the lid slide sideways on its seat. Four
  Ø3 pins on the wall top drop into blind sockets in the skirt and take that
  load instead. Measuring the original confirmed it has no register of its own:
  seated, the two parts meet in a plain butt joint with 0.00 mm of overlap.
- **Per-connector openings on the USB/Ethernet edge.** A continuous sill runs
  under the connectors and full-height dividers stand between them, so each
  connector gets its own window instead of one long slot. The sill is the
  original's idiom (its +X wall stops at Z 9.1 against a 12.4 wall top); the
  dividers are not — RonnyS leaves that edge as a single span.
- **The power/HDMI edge gets the sill but no dividers**, and that asymmetry is
  deliberate. On the USB/Ethernet edge the connectors protrude past the wall's
  outer face (to x 47.79 against 46.5), so a plug never touches the case and the
  sockets alone set the spacing. On the power/HDMI edge they stop at the wall's
  *inner* face, so the plug's overmould passes through the opening — and the two
  micro-HDMI sockets are only 13.5 mm apart, which is already tight for two
  cables on a bare Pi 4. Anything between them would likely stop both going in.
- The fan is **hung off the lid** instead of a separate Pi-mounted bracket —
  a Pi-mounted plate plus fan does not fit the 5-inch stack's headroom.
  Measured against the board models, the fan clears the GPIO header by only
  **1.10 mm**; check it on the real thing before relying on it. It does **not**
  clear a Pi 5 active cooler at all — see below.
- **The stand's foot is a plain blade, not a Y-fork.** The original splays each
  foot into two arms about 56 mm apart, which is what gives a narrow stand its
  sideways stability. Here the two stands are already 103.7 mm apart, so the
  fork earns nothing — and dropping it keeps the part a pure 2-D extrusion in
  print orientation, with no overhanging faces at all. Everything else about
  the fastening matches the original: a flat counterbored strap sharing that
  side's two display case screws.
- The shell keeps **discrete pass-through holes** for the standoffs rather than
  one large rear opening. On the 5-inch panel the case-screw bosses (y ±25.5)
  and the display's own Pi standoffs (y ±28.5) fall in the same band, so an
  opening big enough to clear the standoffs would swallow the screw bosses.
- No wall/V-slot brackets, and no Pi 3 variant.

## Parts and printing

Print in **PETG**. An enclosed Pi 4 can creep toward PLA's glass transition
(~60 °C); PETG's is ~80 °C. It also takes heat-set inserts better and gives the
the stands stronger layer adhesion.

The file list, quantities, print orientations and slicer settings are in
[`BOM.md`](BOM.md), along with the fasteners and cables. This section covers
the choices behind them.

`shell.stl` and the stands are the same for both boards — only `case_bottom`
and `case_top` are cut per model, and they must be a matching pair.

Pick one lean angle and print **both** files for it — one per side:

| Files | Lean | Stand size (mm) | Assembly depth on the desk |
|---|---|---|---|
| `stand_15_usb` + `stand_15_dsi` | 15° | 104.9 × 43.5 × 14.0 | 68.5 mm |
| `stand_20_usb` + `stand_20_dsi` | 20° | 105.4 × 42.3 × 14.0 | 73.9 mm |
| `stand_30_usb` + `stand_30_dsi` | 30° | 108.0 × 39.0 × 14.0 | 83.1 mm |

**30° is the marginal option.** Raising the case moves the centre of mass back,
so the rear tipping margin falls: 25.0 mm at 20° but only 11.5 mm at 30°, where
the strut tip also stops level with the case's own rear edge. It passes, but 15°
and 20° have far more room. Pick 30° for the viewing angle, not for stability.
It is also the angle that limits any further lift — it will fail there first.

The stands hold the case **25 mm** clear of the desk — 3 mm so it never rests on
its own corner, plus a deliberate 22 mm to get the power lead out (see below).
The depth on the desk is unchanged by that lift: it is set by the leaning case's
own silhouette, and the lift moves the case straight up, not backward. The strut
simply tucks a little further underneath.

**The stands are handed** — `_usb` goes on the USB/Ethernet side, `_dsi` on the
ribbon side. They are mirror images, and an L-shaped profile has no mirror
symmetry in either axis, so no amount of turning one round will substitute for
the other. The screw holes sit 2.85 mm from the strap's inboard edge and
11.15 mm from its outboard one; fit the wrong one and the holes simply miss the
case screws by 8.3 mm, so the mistake is obvious rather than subtle.

Why not one symmetric part? The screw is at case X 51.85 and the case's −X wall
is at 48.5, so a symmetric strap could be at most 5.7 mm wide — narrower than
the Ø5.4 counterbore, which would leave the strap as a 1 mm web at both screws.

At every angle the foot stops **inside** the case's own silhouette (3.5 mm in at
15°, 21 mm at 30°), so the stand never sticks out behind the case; the depths
above are set by the leaning case, not by the foot.

The tolerances assume PETG. For PLA, drop `fit_clear` in `shell.py` from 0.5 to
0.4 mm.

## Choosing the board variant

Both boards are 85 × 56 mm on the same 58 × 49 mounting pattern, so the shell,
the stands and the whole screw stack are shared. What differs is the ports.
Connector positions were measured off the reference board models rather than
taken from the board drawings, and live in `pi_models.py`; both scripts derive
their openings from that one table, so the wall gap and the lid aperture cannot
drift apart.

| | Pi 4 | Pi 5 |
|---|---|---|
| USB / Ethernet order on the +X edge | USB2, USB3, Ethernet | Ethernet, USB3, USB2 |
| 3.5 mm audio jack | yes | none |
| Display FPC connector | −X short edge | **−Y long edge** (x 6.7…15.2) |
| Display FPC type | 15-pin | 22-pin (0.5 mm) |
| Tallest point above the PCB | 16.8 mm | 16.4 mm |
| Clearance under the lid | 3.20 mm | 3.58 mm |
| Works with the optional 40 mm fan | yes | only **without** the active cooler |

Both boards carry the same stacked dual USB-A cans, so the tallest points above
should really be identical. The reference meshes disagree with themselves about
this — each models one USB block taller than the other beside it. The Pi 5's was
corrected to the measured-and-fitted value after a printed lid showed a visible
gap over the USB3 can and none over the USB2 one; the Pi 4's 0.4 mm is left as
measured, because that lid is validated on hardware and it has never shown.

Build the pair for that board:

```bash
python case_bottom.py pi5 && python case_top.py pi5
```

### Read this before choosing a Pi 5

**Built and fitted.** Both Pi 5 parts have been printed at the current revision
and confirmed to fit the board. An earlier build found one fault — the USB3
aperture was cut 1.32 mm taller than the USB2 one beside it, from an error in
the reference mesh rather than in these scripts — and the corrected lid has
since been printed and fitted in turn. Nothing about the Pi 5 pair is
outstanding. Feedback welcome.

The Pi 4 case is assembled and in daily service, and is the more travelled of
the two.

**The display ribbon does not route the same way.** On the Pi 4 the DSI socket
is on the short edge nearest the display's own FPC, so the ribbon rises through
the bay and folds straight onto it over about 20 mm. The Pi 5 has nothing on
that edge — both its MIPI connectors are on the −Y long edge, roughly 45 mm
further along — so the ribbon has to run across the top of the board to reach
one. There is room above the PCB for it, but the panel's own cable will not
reach and will not fit.

The part required is a single **Raspberry Pi Display Adapter Cable for Pi 5** —
22-way 0.5 mm pitch at the Pi end, 15-way 1 mm pitch at the display end — which
replaces the panel's cable outright. It is one part, not a cable plus an
adapter. Sold in 200 / 300 / 500 mm lengths; measure the routing before
choosing, as the run climbs through the bay and then crosses the board.

**Display and camera adapter cables are not interchangeable.** The Pi 5's two
MIPI connectors take either, and the cables look nearly identical, so Raspberry
Pi prints `DISPLAY` along the correct one. Check for that word before plugging
anything in.

**The active cooler and the lid fan are mutually exclusive.** The cooler stands
20.90 mm above the case floor where the fan hangs at 17.40 mm — a 3.5 mm clash.
The cooler costs no lid height otherwise (it sits below the USB cans, which
still set the tallest point), so fit the cooler and leave the fan out. The
grille holes still vent.

## Hardware

The fasteners, cables and the optional fan are listed in [`BOM.md`](BOM.md).
Screw lengths are calculated from the stack-up rather than measured, so confirm
the M2.5 × 16 against the panel in hand — the thread depth of the display's own
screw bosses is not published.

The stands add only **1.0 mm** to the case-screw stack — the strap is 3 mm
thick but 2 mm of that is counterbore, so the head drops most of the way in.
The same M2.5 × 16 therefore still works, with about 10 mm of thread in the
display's boss instead of 11 mm. If they feel short, go to × 18.

The Pi is **not** carried by the case. The display's four built-in 15.9 mm
standoffs carry it, via the extenders. One screw chain runs the whole stack:

```
display standoff → 6+6 extender → Pi → 20 mm standoff → lid screw
```

The 20 mm standoff length sets the case height (lid inner face lands at
Z 27.4, clearing the USB connector cans by 4 mm). Substituting a different
length means changing `standoff` in `case_top.py` and re-running it.

## Assembly

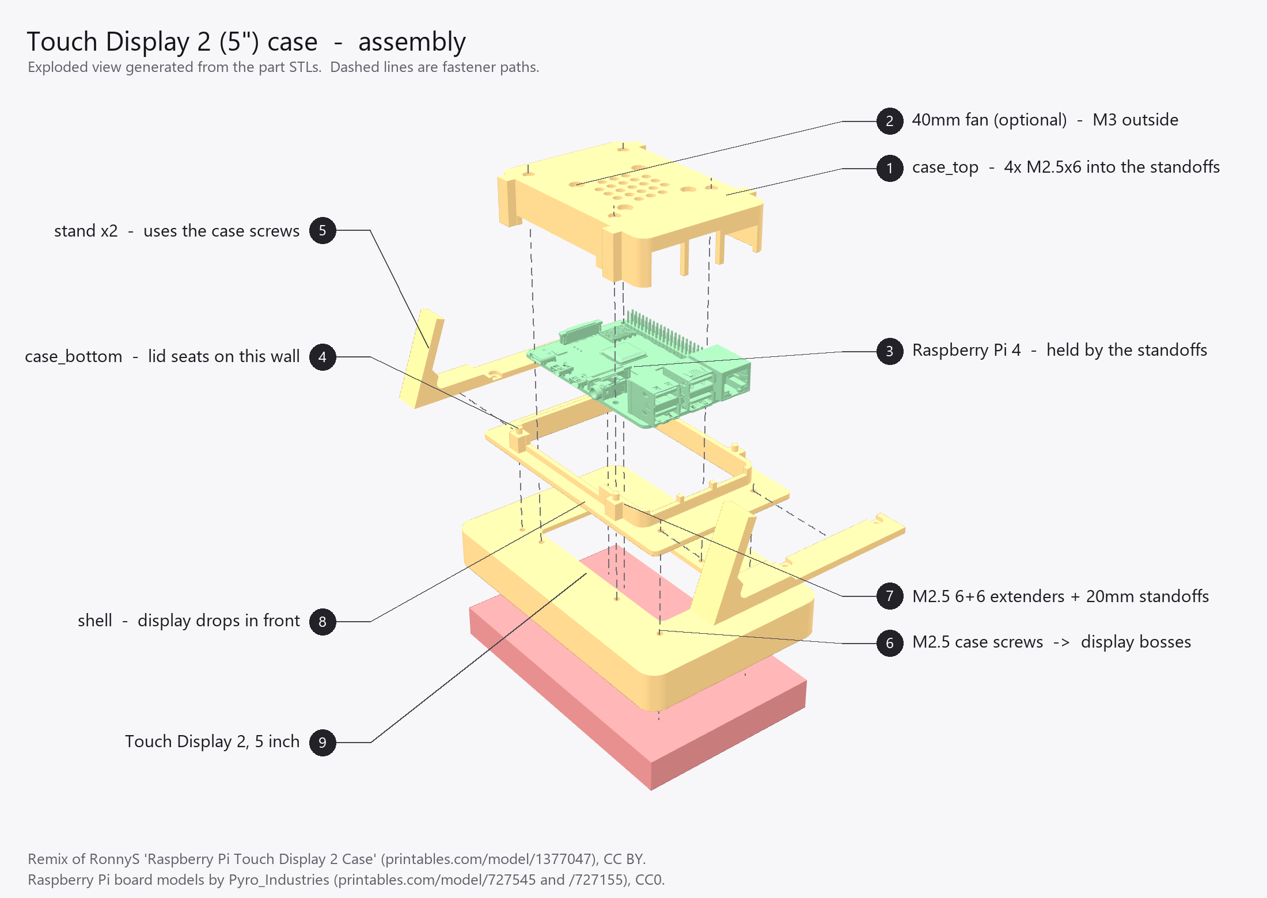
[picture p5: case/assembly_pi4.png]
Exploded assembly diagram, Pi 4 variant


*Building the Pi 5 variant instead? The same diagram for that board is
[`assembly_pi5.png`](assembly_pi5.png) — the assembly steps below are identical,
only the port openings differ.*

The numbered callouts match the steps below. The diagram is generated from the
part STLs by `assembly_diagram.py`, so it cannot drift from the geometry —
re-run that script after changing any part.

1. Drop the display into the **shell** from the front. It is retained by the
   sandwich, not screwed to the shell.
2. Screw the four **M2.5 6+6 extenders** through the shell's back plate into the
   display's built-in standoffs (58 × 49 pattern).
3. Fit the **case-bottom** over the extenders, lay a **stand** on each side
   flange with its strut pointing down and back — `_usb` on the USB/Ethernet
   side, `_dsi` on the other — and run the four **case screws** (103.7 × 51
   pattern) through both into the display's screw bosses. Each stand's screw
   slots open toward the **middle** of the case; if they face outward the pair
   is swapped. A driver reaches all four screws even with the Pi and lid
   fitted, provided the +X cables are unplugged, so the lean angle can be
   changed later without taking the case apart — and because the slots are open,
   **slacken the screws by a few turns and slide the stand off sideways**
   rather than removing them.
4. Plug the **DSI ribbon** into the display, then seat the Pi on the extenders.
   The display's socket sits under the board, so bring the ribbon up through
   the bay, **wrap it around the board's DSI edge** and fold it onto the socket
   on the Pi's top face. Lay the slack **flat over the top of the Pi**. Do not
   bunch it underneath. *(Pi 5: the socket is on the long edge instead — run
   the ribbon across the top of the board to reach it.)*
5. Screw the four **M2.5 × 20 standoffs** down through the Pi's mounting holes
   into the extenders. These clamp the Pi and provide the lid's threads.
6. Optional: screw the **fan** to the lid from the outside (32 × 32 pattern).
7. Fit the **lid**. Line the four **sockets in the skirt** up with the four
   spigots on the wall top and press it down — the skirt seats on the wall and
   the spigots take up the side play. If it will not sit flush, a spigot has
   missed its socket; do not force it down with the screws. Then secure with
   four **M2.5 × 6** screws through the top face into the standoffs.

The spigots are a Ø3.0 pin in a Ø3.5 socket, so the lid can still shift about
0.25 mm before they bite — enough to assemble reliably in PETG, which prints
slightly proud. If they end up too tight to seat, or too loose to feel like
they are doing anything, change `spigot_fit` in `case_top.py` and re-print the
lid; the pin is not affected.

## The stands

Each stand is an **L**: a flat strap that lies on the case-bottom's rear face
and carries both case screws, and a strut that leaves the strap's bottom end
and lies flat in the desk plane. There is deliberately **no diagonal brace**
between the two.

That absence is the whole design. A brace would have to cross the Pi's +X port
band, which is what sank the previous side-flange leg: its arm occupied
Z 2.5–11.5 while the USB and Ethernet **connector shells start at Z 6.65** —
0.75 mm *below* the PCB's top face, not level with it — so the bottom of every
plug fouled it. Here nothing crosses that band. The strap passes underneath it
(3 mm thick, clearing the plugs by 1.15 mm) and the strut stays outboard of it
in Y, by 4.9 mm at every angle.

Both members step in thickness, with the same 45° chamfer and the same 2:1
ratio. The strap is **3 mm across the port band and 6 mm past it**; the strut
is **9 mm at its root and 4.5 mm beyond 20 mm along the desk**. The strut's
bending moment is largest where it meets the strap and zero at the tip, so the
material out there was doing nothing — and thinning it also pulls the strut's
inner edge away from the plug band, which is what used to limit the 30°
variant to 2.9 mm of clearance. It can afford to be thin because the strut's root is itself a
desk contact — the toe touches down right where the strut meets the strap — so
the strut carries its load straight to the desk in compression and the strap
sees almost no bending. The thick section exists for the case where a print
tolerance lifts the toe slightly and the strap does have to take it.

Screw heads sit in **Ø5.4 × 2 mm counterbores**, which puts the head top at
Z 6.00 against the plugs at 6.65 even for a tall socket-cap head. The
counterbore is 0.7 mm wider than the head because it is a horizontal bore in
print orientation and its roof droops a little.

**Both screw features are open slots, not holes**, running out through the
strap's **inboard** edge — the side facing the middle of the case. The
counterbore has to be: the screw axis is only 2.85 mm from that edge, so a
plain circular pocket would leave a 0.15 mm fin standing 2 mm tall, which would
just break off. The Ø2.9 through-hole is slotted for a different reason — so a
stand can be **slid on and off with the case screws merely slackened**, rather
than withdrawn. Taking them right out means holding the display, shell and
case-bottom together unaided, which is the awkward part of changing the lean
angle.

The mouths face inboard because that is the only direction that works: the
stand is offered up about 3 mm outboard of its seated position, overhanging the
free edge of the plate, and slid inward onto the screws. Mouths on the outboard
edge would need it to start 2.85 mm further *in*, driving its inboard edge
straight into the case's −X wall. The consequence is that nothing locates the
stand along X any more except friction under the screw heads — which is fine in
service, because the case's weight acts across the slots rather than along
them, but do tighten both screws before letting go.

Nothing here is compliant — no spring, no latch, no sustained strain — so
unlike the snap-on design it replaces, there is no creep to design around and
nothing whose grip depends on holding a 0.2 mm clearance.

**Releasing an Ethernet cable needs a small screwdriver.** The Pi 4's RJ45 jack
has its retention clip on the *underside*, and the strap passes 1.15 mm beneath
it, so there is no room for a fingertip — lift the clip with a thin blade
instead. Confirmed on hardware; easy enough, just not obvious. This is mostly
inherent to the case rather than the stand: with the strap removed entirely the
gap would only grow to 4.15 mm, because the case-bottom's own plate is at
Z 2.50. Both USB and Ethernet cables otherwise plug in and seat normally.

### Power lead clearance — why the stands lift the case

The power socket faces down toward the desk. On the original 7-inch case the
body is tall enough to swallow a straight plug; at 5 inches it is not, and this
is the one place the smaller scale really bites. Before the lift there was only:

| Lean | Room from the socket face to the desk | With the 22 mm lift |
|---|---|---|
| 15° | 17.4 mm | **40.2 mm** |
| 20° | 16.6 mm | **40.0 mm** |
| 30° | 15.7 mm | **41.1 mm** |

A straight plug's overmould, plus the bend the lead needs before it can run
flat, is far longer than the original figures — in practice **even a right-angle
adaptor's overmould did not fit**. So the stands raise the whole case by a
deliberate 22 mm (`lift` in `stand.py`), on top of the 3 mm that keeps it off
its own corner.

Every one of those figures was set on hardware, not modelled. 10 mm cleared a
right-angle adaptor. 20 mm got the **official Raspberry Pi power supply** in but
only just — its captive cable is thick and has very little flex, so it cannot
turn tightly and was still working against the desk. **22 mm is the printed and
fitted answer.** It is sized for the supplied PSU deliberately — most people
printing this case will have one, and "the power supply in the box does not fit"
is a bad thing to discover after a print.

Two things worth understanding about that fix:

- **Leaning further back makes the problem worse, not better** — it brings the
  socket closer to the desk. The lift is perpendicular to the desk, so it buys
  `lift / cos(tilt)` along the plug axis. That is why all three angles land at
  about the same 40 mm: the lift cancels the penalty for leaning back.
- **It improves the front tipping margin** rather than hurting it, from 12.0 mm
  unlifted to 20.0 mm at 20°. The strap lies on the *tilted* rear face, so
  extending it moves the toe down **and forward**, widening the front contact
  faster than the rising centre of mass eats it. The rear margin gives up the
  same amount and still has 25 mm at 20°. Don't assume raising a leaning case
  costs stability — but see the 30° warning above, because that is where the
  rear margin runs out first.

The toe still sits 11.3 mm behind the glass edge at 20°, so nothing protrudes in
front of the display.

To change the lean angle, unplug the +X cables, undo the four case screws, swap
both stands and do them back up. The Pi and lid can stay where they are.

## Panel geometry

The **built-in Pi standoffs** — the four 15.9 mm towers on the panel's rear, in
the Pi's 58 × 49 pattern, which the extenders screw into — are **not centred**
on the panel. Measured on a real 5-inch unit:

- along the **long** axis: **34 mm** from the DSI/connector edge, 51.5 mm from
  the other (34 + 58 + 51.5 = 143.5)
- along the **short** axis: **21 mm** from each edge (21 + 49 + 21 = 91), i.e.
  centred

That gives `ext_off_x = -8.7`, `ext_off_y = 0` in `case_bottom.py` and
`shell.py`, placing the Pi board at x −41.2 … 43.8. Everything downstream — the
bay, the wall positions and the lid's port apertures — follows from it, so if a
panel measures differently, change those two values and re-run all three
scripts.

Do not confuse these with the **103.7 × 51 screw bosses**, which sit 5.5 mm
lower on the panel and take the case screws.

One consequence worth knowing: the display's DSI socket ends up *underneath*
the Pi board (2 mm from the Pi's own DSI socket), so the ribbon rises through
the bay, wraps around the board's DSI edge — there is 4.8 mm of bay past that
edge for the fold — and lands on the socket on the top face.

The DSI connector position (`ffc_x`) needs no check — the display's socket sits
essentially directly below the Pi's, and the bay clears it by 4.5–8.5 mm across
that range.

## Adjusting

Every part is a parametric CadQuery script; edit the `PARAMETERS` block and
re-run to regenerate the STL:

```bash
python shell.py
```

Useful knobs:

| Parameter | File | Effect |
|---|---|---|
| `tilts` | `stand.py` | which lean angles to export (default 15/20/30°) |
| `fit_clear` | `shell.py` | display pocket clearance (PETG 0.5, PLA 0.4) |
| `foot_len` | `stand.py` | stand depth — how far back the foot reaches |
| `foot_t`, `foot_t_thin`, `foot_step` | `stand.py` | strut thickness at the root, past the step, and where it steps |
| `strap_t_thin` | `stand.py` | strap under the port band — raising it eats the 1.15 mm plug gap |
| `grille_r`, `grille_pitch` | `case_top.py` | fan grille pattern |
| `spigot_fit` | `case_top.py` | lid socket clearance — how much play before the spigots bite |
| `port_clear`, `min_divider` | both | clearance around each connector, and the thinnest divider allowed |
| `bot_sill_clear` | `case_bottom.py` | how far the power/HDMI sill sits below the sockets |

**`bot_sill_clear` is the least certain number in the case.** Nothing here
measures how far a plug's overmould hangs below its socket, so it is set to a
deliberately generous **2.0 mm**, putting the sill top at Z 5.35 on a Pi 4 and
6.00 on a Pi 5.

One flat sill spans the whole opening, so this is the margin under the **lowest**
socket — the **USB-C** on both boards, which is the one to check first if
anything fouls. Every other port on that edge gets at least as much: on a Pi 4
the micro-HDMIs and the audio jack clear the sill by 2.65 mm. If a particular
cable still will not seat, raise this value and re-print the case-bottom.

The USB/Ethernet sill needs no such margin (0.35 mm), since no plug ever reaches
it.

Port geometry is not edited directly: it comes from the measured tables in
`pi_models.py`. Correct a connector there and both parts follow.

`strap_x0` / `strap_x1` in `stand.py` must match `stand_strap_x0` and `half_x`
in `case_bottom.py` — they are the two ends of the flange the strap sits on.

The scripts carry assertions for the clearances that matter (ribbon, Pi
footprint versus the walls, screw ligaments, fan-screw versus grille), so a
parameter change that would cause a collision fails loudly instead of producing
a bad STL. `stand.py` additionally checks its whole profile against the Pi's
measured plug keepout at every tilt, allowing 2 mm for the one Pi-position
number never verified on a real panel.

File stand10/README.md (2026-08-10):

# 🖥️ Stand — Raspberry Pi Touch Display 2 (10.1")

A 3D-printable desk stand for the **10.1-inch** Raspberry Pi Touch Display 2
with a Raspberry Pi 5 mounted on its back. One printed part, two screws, a 10°
backward lean.

The 10.1" panel needs no enclosure — the Pi bolts to the standard 58 × 49 mm
pattern in the middle of the back plate, and its active cooler wants free air.
Only a way to stand the panel on a desk is missing.

**Highlights**

- One part, two M2.5 screws, no other fasteners.
- 41.5 g of PETG, 2 hours 3 minutes, no supports and no brim.
- No printed part appears below the bezel.
- Bolts to the lower bracket pair only, clear of the DSI ribbon.
- Two moulded-in collars carry the power lead down the back to the desk.

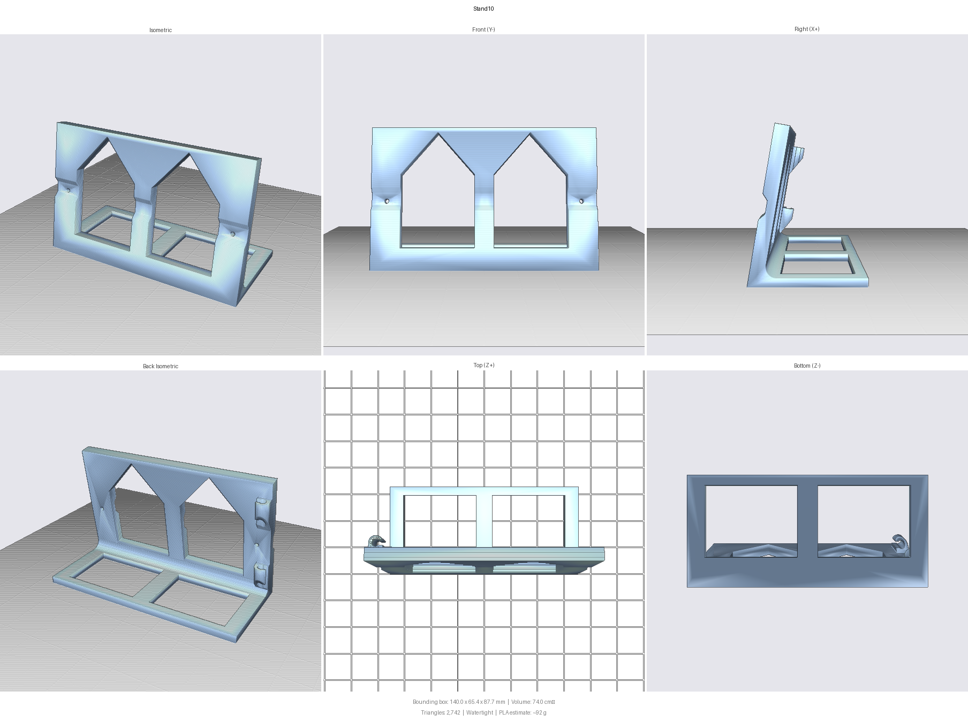
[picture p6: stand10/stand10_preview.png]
Six views of the stand: an L in section, 140 mm across, with an upright leaning back 10 degrees carrying two gabled windows and a screw hole in each outer column, and a foot reaching 65 mm backward with two rectangular windows. Two cable collars stand proud of the upright's back face at one outer e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


## ⚠️ Panel orientation

> [!WARNING]
> **The panel mounts 180° from the way it arrives.** The part does not fit the
> other way up.

The two bracket pairs sit at different offsets from their nearest short edge,
and the Pi is not centred vertically. Mounted as delivered, only 14 mm of back
plate is clear above the lower brackets before the board begins. Turned over,
59 mm is clear.

The image and touch mapping are turned to match by `build10/display.py`
(`ROTATE_DEG = 180`). **No change to `/boot/firmware/config.txt` is required.**

> [!NOTE]
> The DSI overlay's `rotation=180` has no effect on this display, which writes
> straight to `/dev/fb0`. Its `invx,invy` do work, but must not be set as well
> — they cancel against the software mapping and invert every tap.

## 🔧 Requirements

| | |
|---|---|
| Panel | Raspberry Pi Touch Display 2, 10.1", Pi already mounted |
| Screws | **2 × M2.5 × 12 mm**, pan or socket head |
| Power lead | 4 mm across the jacket — see [Cable routing](#-cable-routing) |
| Filament | PETG, 41.5 g |
| Print bed | 140 × 65 mm minimum, 88 mm height |

M2.5 × 12 is confirmed on hardware. The bosses are threaded 8 mm deep and the
pad is 5 mm thick, giving 7 mm of engagement without bottoming out.

## 🖨️ Printing

```
PETG, 0.2 mm layer, 3 walls, 20% infill, no supports.
Orientation: foot flat on the bed, upright rising — as modelled, no rotation.
```

PETG rather than PLA because the panel is an always-on device in a warm room:
PETG's glass transition is ~80 °C against PLA's ~60 °C.

No supports and no brim are needed. The upright leans 10°, the window gables
are pitched past 45°, and the foot puts about 4,600 mm² on the bed. The only
downward-facing surfaces are the two screw bores, which span 2.9 mm and bridge.

The cable collars keep that true. Each is a ring extruded along the panel's own
up direction, so it leans back with the upright rather than presenting a new
overhang, and each sits on a plinth sloped at 50° that carries its projection
back to the wall. `check_stand10.py` measures the result: the downward-facing
area is the same 22.4 mm² with the collars as without them, and PrusaSlicer
flags no support-requiring geometry.

The weight and time above are taken from that slice rather than estimated.

## 🔩 Assembly

1. Rest the panel face-down on something soft, turned 180° from its delivered
   orientation — the Pi's port face at the **top**.
2. Offer the stand up to the lower bracket pair. The flat pads around the screw
   holes sit on the bosses; the faces above and below them come to rest against
   the back plate itself.
3. Run an M2.5 × 12 through each hole into the boss. Firm, not tight — there is
   no washer face, and PETG dishes if over-torqued.
4. Stand the assembly up.
5. Press the power lead into the two collars — see below.

The model leaves the panel's bottom edge 2 mm above the desk (`clear_z`). On the
assembled article that edge comes to rest on the desk instead, so the desk takes
part of the weight and the two screws carry the rest in shear. Either way no
printed part appears below the bezel, which is what the clearance is there for.

## 🔌 Cable routing

Without help the power lead leaves the Pi at the top of the panel and hangs out
to the side and behind. Two collars on the back of the upright take it down to
the desk instead.

Bring the lead down the same side of the panel as the Pi's power socket, then
press it into the upper collar and the lower one in turn. Each mouth is 3.6 mm
against a 4 mm lead, so the jacket has to squeeze slightly going in; that is
what stops it falling out again.

**The two mouths deliberately face opposite ways.** The lead cannot leave
without moving in two directions at once, so retention does not depend on a
lip springing open and shut — which matters, because PETG at this section does
not flex much. If the mouths prove too tight in practice, raising `clip_mouth`
above `clip_bore` turns them into plain open channels and the opposed
directions still hold the lead in place.

The collars sit as far outboard as they fit on the bolt column, because the
lead's overmould and its own stiffness need room to turn: the further out the
run, the wider the radius it can take. The upper collar stops 10 mm short of
the top of the upright for the same reason.

> [!NOTE]
> There are two collars rather than three because of the bolt line. Counting
> its plinth, each collar occupies about 24 mm of vertical run, and the bolt
> head has to stay reachable — which leaves room for one collar below it and
> none between it and the upper collar.

## 📐 Key dimensions

All in the mounted orientation, i.e. after the 180° turn.

| | |
|---|---|
| Stand | 140 × 65 × 88 mm |
| Panel outline | 167 × 247 mm |
| Lower bosses | 121.8 mm apart, 41 mm up from the bottom edge |
| Bosses | M2.5, 3 mm proud of the back plate, 8 mm thread depth |
| Pi, port face to SD end | 100 – 187 mm up the back plate |
| Mass, panel + Pi | 558 g |

## 🛠️ Troubleshooting

**The assembly rocks on the desk.** The front face is meant to touch the back
plate both above and below the screws. If only one side is touching, check that
the pads are seated squarely on the bosses and that neither screw is
over-tightened.

**The stand fits, but at the wrong end of the display.** The panel is the wrong
way up — see [Panel orientation](#️-panel-orientation).

**The top of the stand fouls the DSI ribbon.** The ribbon loops under the board
and hangs below it. The upright stops at 87 mm to clear it; a taller value in
`stand10.py` will press on the loop.

**The lead will not go into the collars.** The mouths are 0.4 mm narrower than
a 4 mm lead by design. A thicker lead needs `CABLE_D` set to its own diameter
and the part reprinted; a lead that will not squeeze needs `clip_mouth` raised
above `clip_bore`, which leaves the opposed mouths doing the retaining.

**The collars are on the wrong side.** They are on one bolt column only. Flip
`clip_x_sign` in `stand10.py` and reprint.

**Taps land diagonally opposite the finger.** Both the software mapping and the
overlay's `invx,invy` are inverting the touchscreen. Remove the overlay
parameters.

## ⚙️ Parameters

Every dimension is a parameter at the top of `stand10.py`. Rebuild and verify
with:

```bash
python stand10.py && python check_stand10.py
```

| Parameter | Default | Effect |
|---|---|---|
| `tilt` | 10.0 | Backward lean, degrees |
| `foot_depth` | 65.0 | Rearward reach; sized for the hanging cable, not the panel |
| `clear_z` | 2.0 | Modelled gap under the panel's bottom edge; the assembled edge rests on the desk |
| `stand_w` | 140.0 | Width across; stays hidden behind the 167 mm panel |
| `bear_s1` | 87.0 | Top of the upright; limited by the DSI ribbon |
| `hole_d` | 2.9 | M2.5 clearance |
| `CABLE_D` | 4.0 | Power lead across the jacket; sets the bore and the mouth |
| `clip_mouth` | 3.6 | Gap the lead is pushed through; raise past `clip_bore` for open channels |
| `clip_x_sign` | −1.0 | Which bolt column carries the collars; −1 is the right hand side seen from behind |
| `clip_top_clear` | 10.0 | Upper collar's distance below the top of the upright |
| `clip_ramp` | 50.0 | Plinth slope under each collar, in the printer's frame |

## 📄 Licence and credits

**GPL-3.0**, as the rest of this repository. This differs from
[`case/`](../case), which is CC BY as a remix of RonnyS's Touch Display 2 case.
Nothing here derives from that work, so the attribution requirement does not
apply. Credit is welcome, not required.

Issues and suggestions are welcome via the repository's issue tracker.

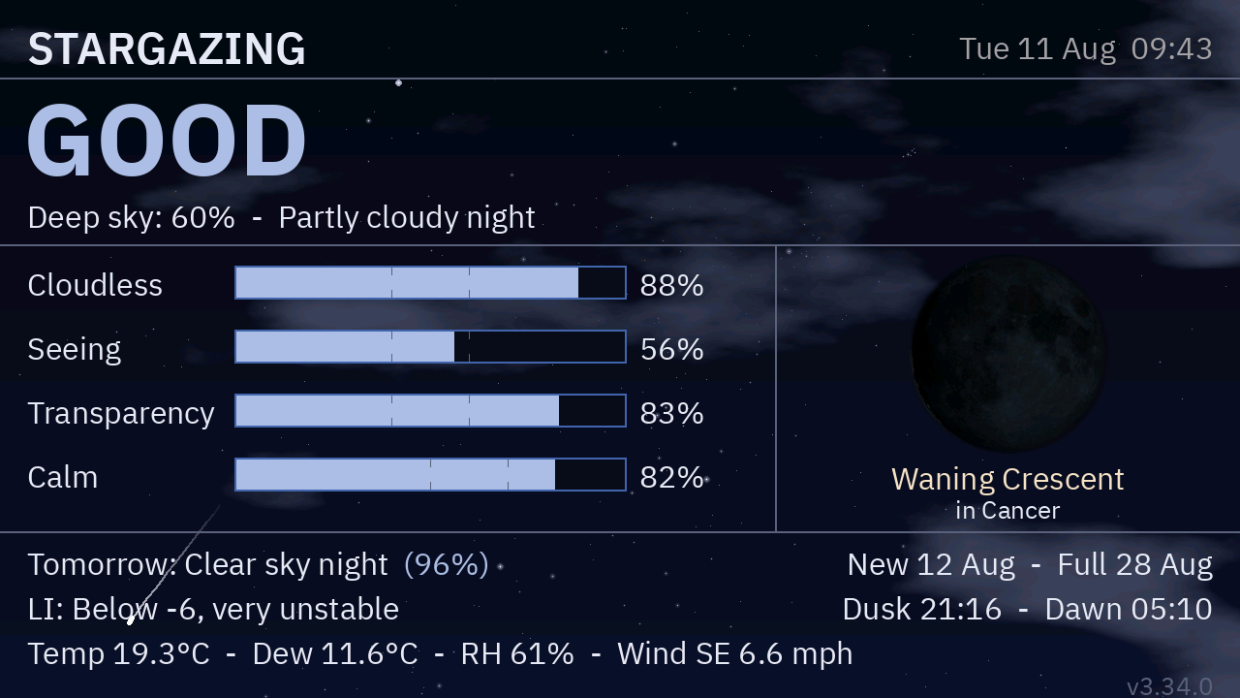
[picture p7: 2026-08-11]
screenshots/conditions.png

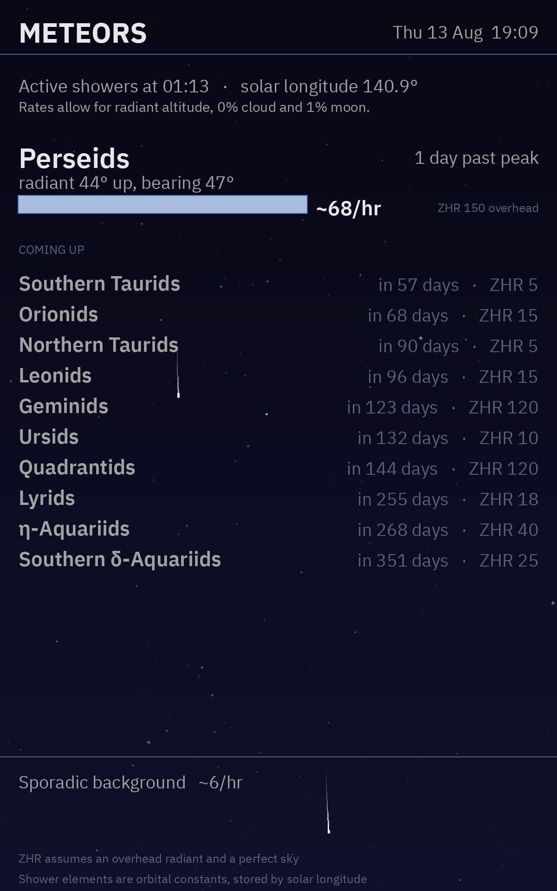
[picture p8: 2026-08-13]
screenshots/10in-meteors.png

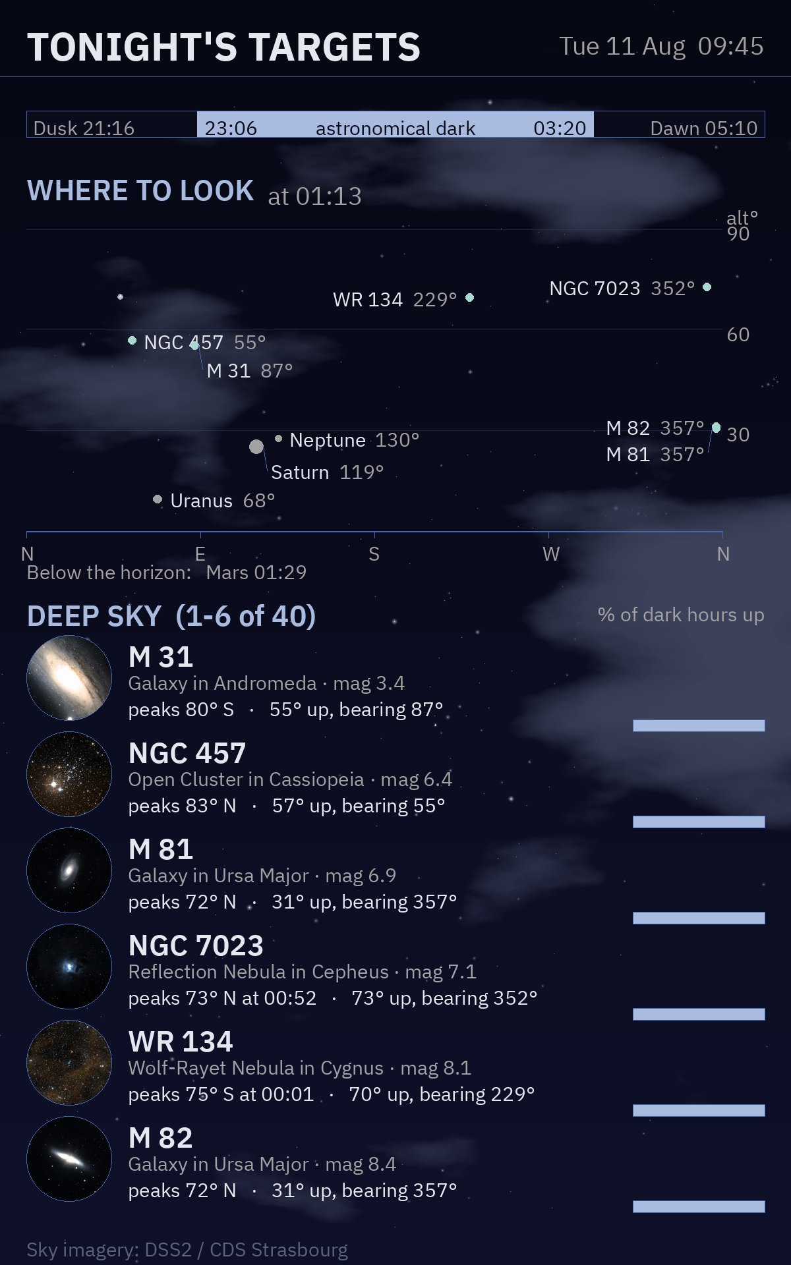
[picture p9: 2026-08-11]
screenshots/10in-targets.png

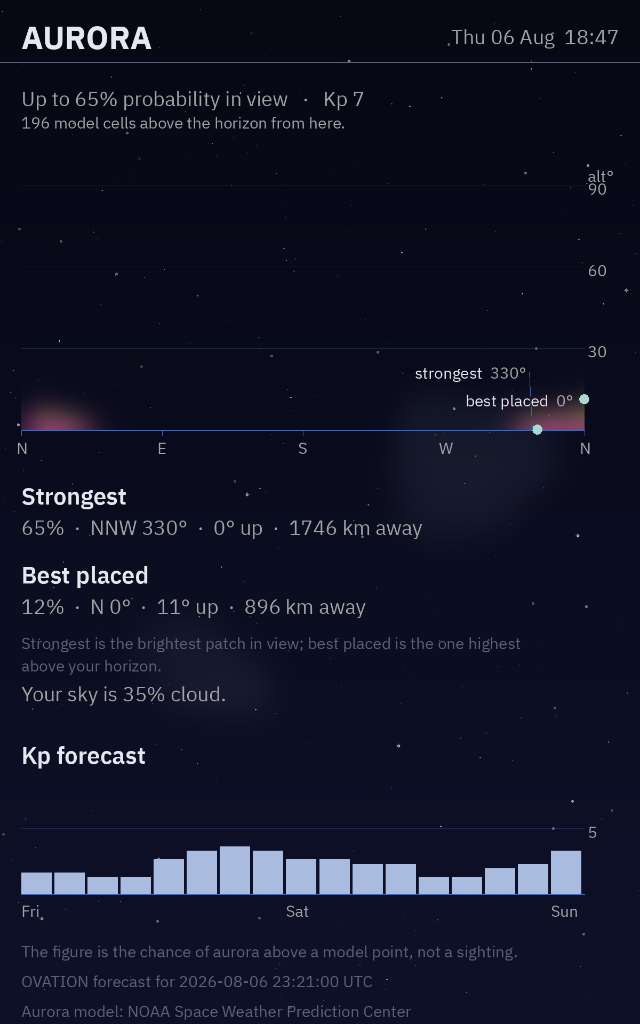
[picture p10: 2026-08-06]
screenshots/10in-aurora-simulated.png

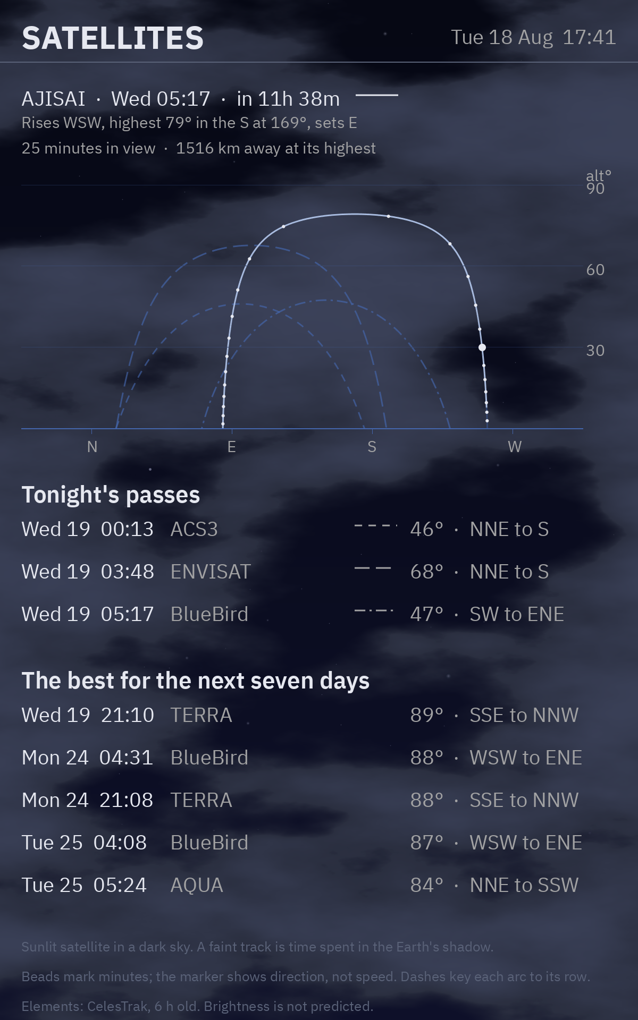
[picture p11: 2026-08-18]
screenshots/10in-satellites.png

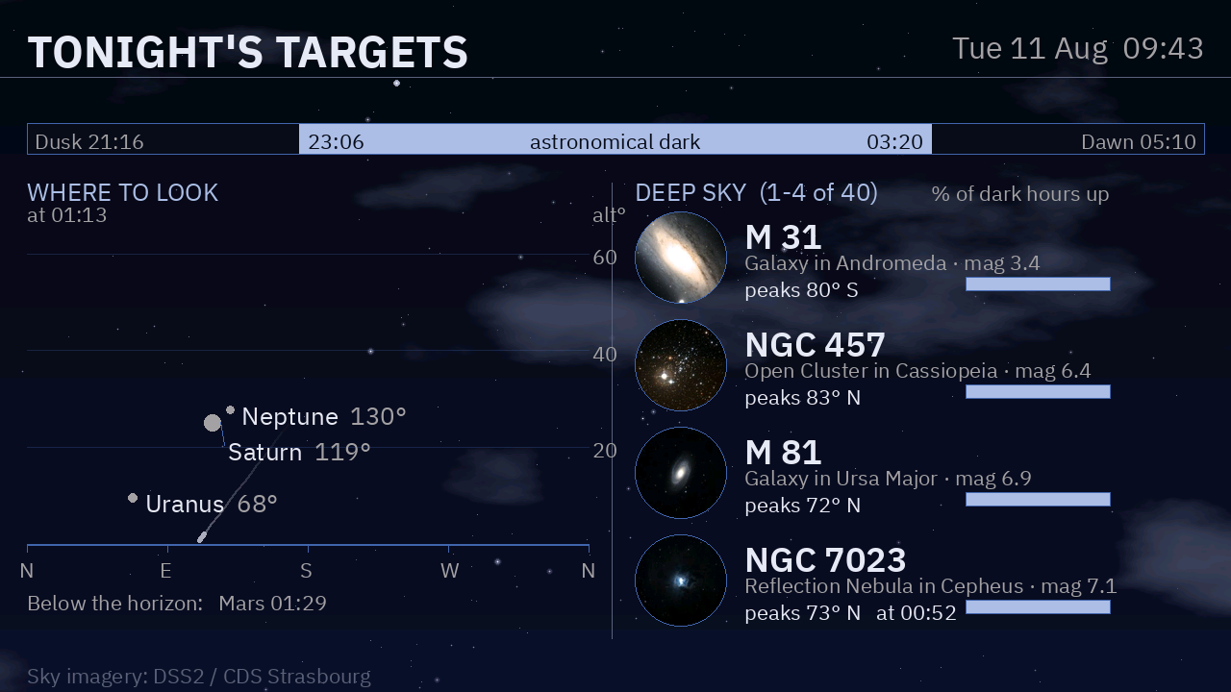
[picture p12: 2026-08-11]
screenshots/targets.png

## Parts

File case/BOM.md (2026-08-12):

# Bill of materials — Touch Display 2 (5") case

Everything needed to build the case, in one list. Design reasoning, assembly
order and the parameters behind these figures are in [`README.md`](README.md).

## Two choices to make first

Both affect which files are printed, and neither can be changed by editing the
list below.

**Board variant — Pi 4 or Pi 5.** The shell and the stands are shared; only
`case_bottom` and `case_top` are cut per board, and they must be a matching
pair. The Pi 5 additionally needs a display adapter cable.

**Lean angle — 15°, 20° or 30°.** Two stand files per angle, one per side. 20°
is the default. The 30° pair is the marginal one for rear tipping margin; see
the README before choosing it.

## Printed parts

PETG, 0.2 mm layer, 3 walls, 20 % infill, **no supports** — every part is
oriented so nothing overhangs beyond 45°.

| File | Qty | Size (mm) | Orientation | Mass | Time |
|---|---|---|---|---|---|
| `shell.stl` | 1 | 149.4 × 97.5 × 18.9 | back plate **down** | 49.1 g | 1 h 54 min |
| `case_bottom_pi4.stl` *or* `case_bottom_pi5.stl` | 1 | 126 × 76 × 13.5 | plate **flat**, wall up | 17.5 g | 48 min |
| `case_top_pi4.stl` *or* `case_top_pi5.stl` | 1 | 95 × 71 × 19.9 | outer face **down** (as exported) | 27.6 g | 1 h 23 min |
| `stand_<angle>_usb.stl` + `stand_<angle>_dsi.stl` | 2 | 105.4 × 42.3 × 14.0 at 20° | **flat** on the profile | 6.5 g each | 41 min for the pair |

**Around 107 g of PETG and 4 h 46 min in total**, printing the stands together
and the other three parts separately.

Every figure above is from PrusaSlicer at the settings in this section, for an
**unmodified Prusa Core One**. Both are machine- and profile-dependent — times
especially, which will not transfer to a different printer. The masses were
taken on the Pi 5 pair; the Pi 4 pair differs only in the port windows.

The stands are handed: `_usb` goes on the USB/Ethernet side, `_dsi` on the
ribbon side. They are mirror images and cannot substitute for one another.

For PLA, drop `fit_clear` in `shell.py` from 0.5 to 0.4 mm before slicing. PETG
is preferred — an enclosed Pi 4 can creep toward PLA's glass transition.

## Fasteners

| Item | Qty | Purpose |
|---|---|---|
| M2.5 × 6+6 male-female standoff | 4 | extenders; relay the Pi mount plane past the case |
| M2.5 × 20 male-female standoff | 4 | clamp the Pi and take the lid screws |
| M2.5 × 6 screw | 4 | lid into the 20 mm standoffs |
| M2.5 × 16 screw | 4 | case screws: stand → case-bottom → shell → display |

**No heat-set inserts and no soldering** — everything threads into a standoff.

The M2.5 × 16 length is calculated from the stack-up rather than measured, since
the thread depth of the display's own screw bosses is not published. Confirm it
against the panel in hand; if the screws feel short, go to × 18.

## Electronics and cables

| Item | Qty | Notes |
|---|---|---|
| Raspberry Pi Touch Display 2, 5-inch | 1 | 91.46 × 143.4 mm panel |
| Raspberry Pi 4 or Pi 5 | 1 | must match the printed `case_bottom` / `case_top` pair |
| USB-C power supply | 1 | the official Raspberry Pi PSU fits — the stands lift the case 22 mm specifically so it does |
| Display Adapter Cable for Pi 5, 22-way → 15-way | 1 | **Pi 5 only.** Replaces the panel's own cable |

The Pi 5 adapter cable is a single part, not a cable plus an adapter, and is
sold in 200 / 300 / 500 mm lengths — measure the routing before choosing, as the
run climbs through the bay and then crosses the board. It must be the one
printed `DISPLAY`; camera adapter cables fit the same connectors and look nearly
identical.

## Optional — 40 mm fan

| Item | Qty | Notes |
|---|---|---|
| 40 × 40 × 10 mm 5 V fan | 1 | hangs off the lid, 32 × 32 screw pattern |
| M3 self-tapping screw | 4 | through the lid from outside |

The fan clears a Pi 4's GPIO header by only 1.10 mm; check it against the real
board before relying on it. It does **not** clear a Pi 5 active cooler — the
two are mutually exclusive, and the cooler is the one to keep. The lid's grille
holes still vent without a fan fitted.

## Tools

- Driver for M2.5 screws
- A thin blade or small screwdriver, to release an Ethernet cable after
  assembly — the RJ45 clip is on the underside of the jack and the stand's strap
  passes 1.15 mm beneath it, leaving no room for a fingertip

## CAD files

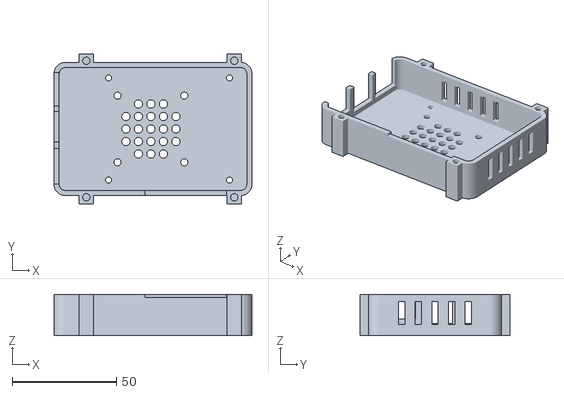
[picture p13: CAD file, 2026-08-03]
case/case_top_pi5.stl
95.0 x 72.0 x 19.9

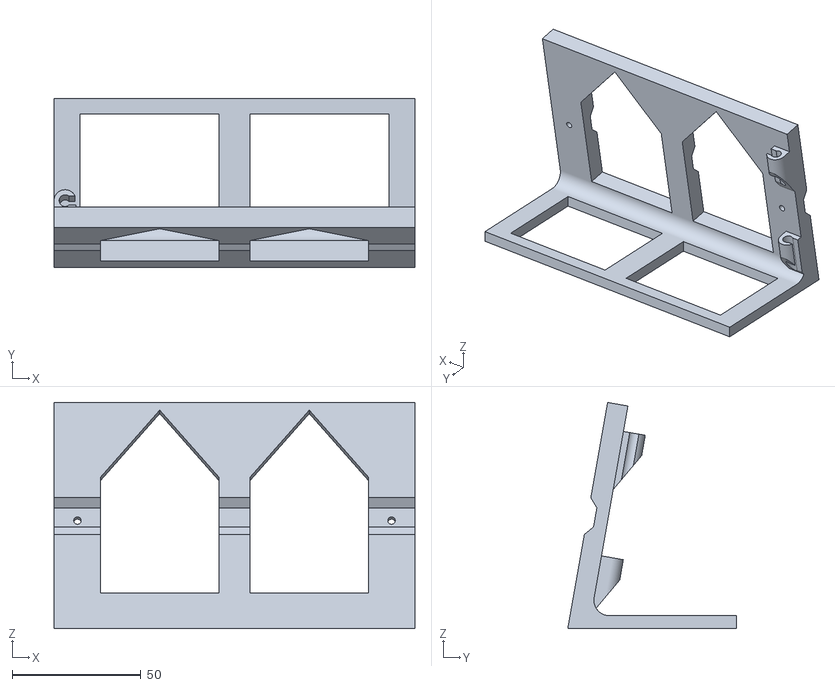
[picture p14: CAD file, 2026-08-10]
stand10/stand10.stl
140.0 x 65.4 x 87.7

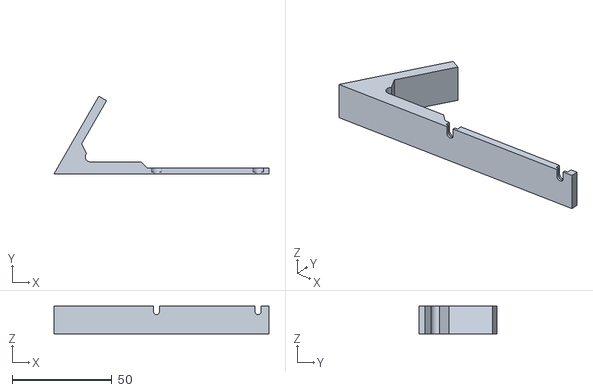
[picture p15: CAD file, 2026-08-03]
case/stand_30_dsi.stl
108.0 x 39.0 x 14.0

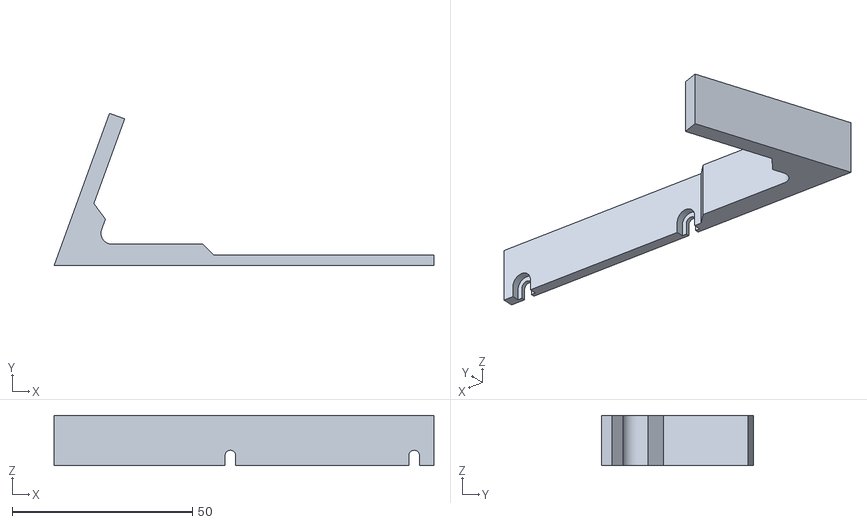
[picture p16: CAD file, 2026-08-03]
case/stand_20_usb.stl
105.4 x 42.3 x 14.0

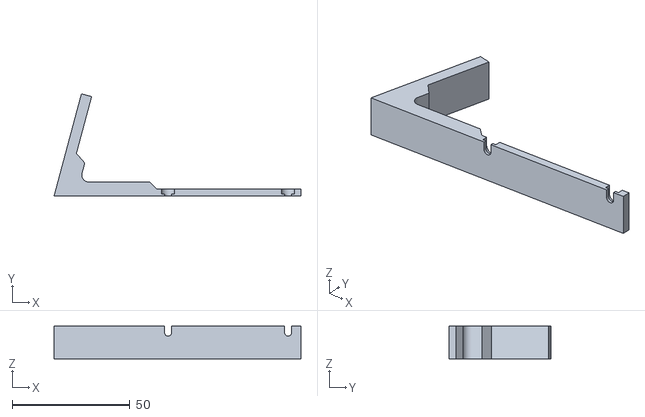
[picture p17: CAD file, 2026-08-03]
case/stand_15_dsi.stl
104.9 x 43.5 x 14.0

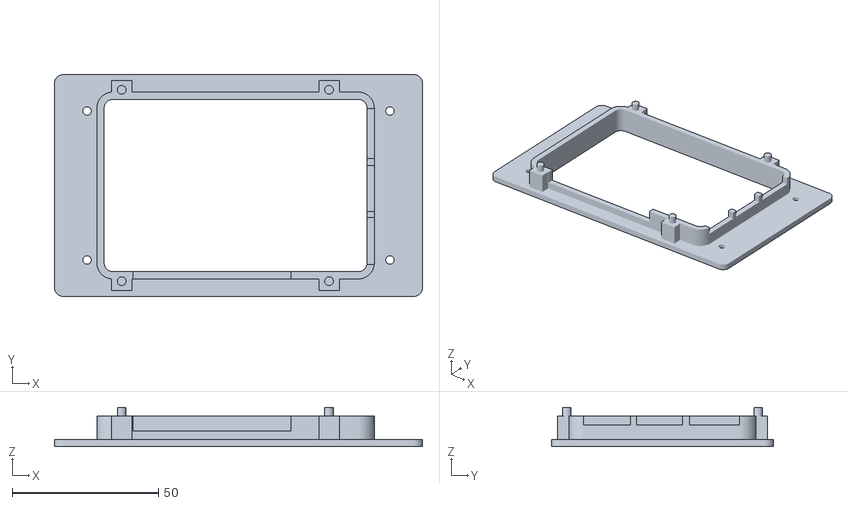
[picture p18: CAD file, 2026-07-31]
case/case_bottom_pi4.stl
126.0 x 76.0 x 13.5

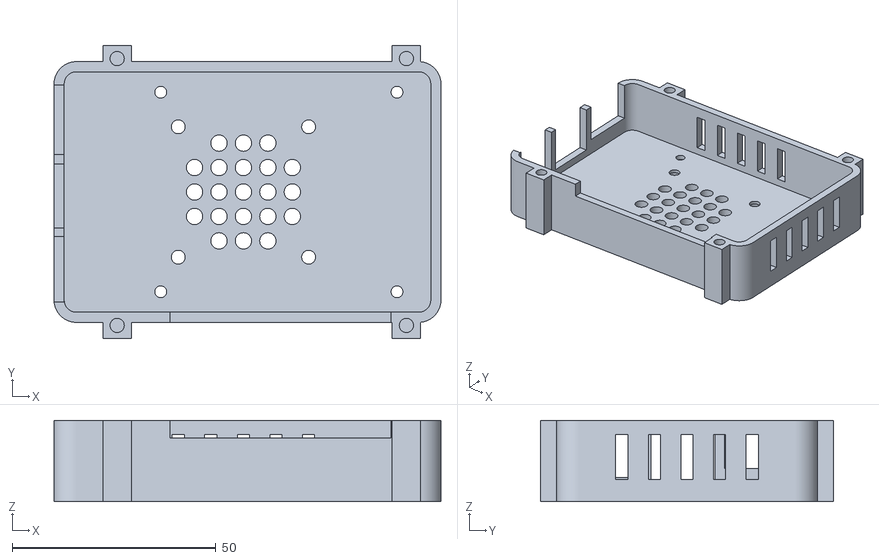
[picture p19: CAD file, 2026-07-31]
case/case_top_pi4.stl
95.0 x 72.0 x 19.9

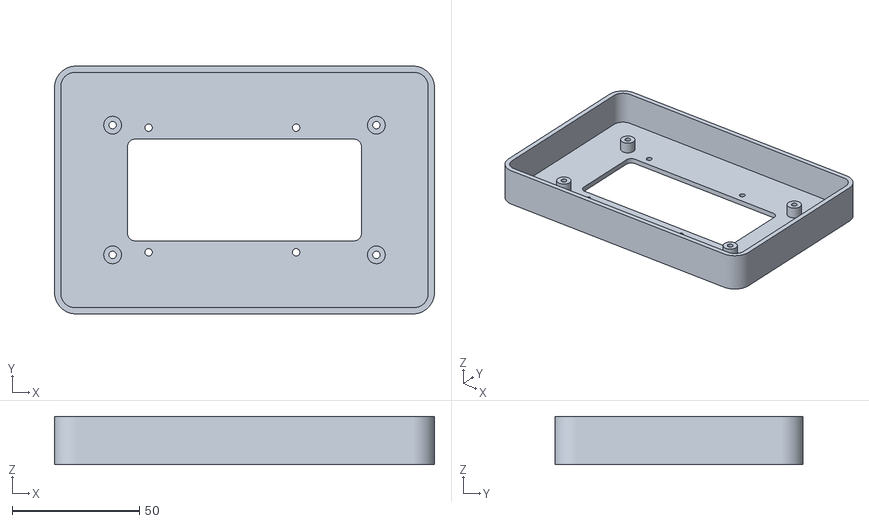
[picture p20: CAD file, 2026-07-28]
case/shell.stl
149.4 x 97.5 x 18.9

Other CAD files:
case/stand_30_usb.stl
case/stand_15_usb.stl
case/stand_20_dsi.stl
case/case_bottom_pi5.stl

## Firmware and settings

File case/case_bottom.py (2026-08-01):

"""Pi case-bottom for the Touch Display 2 (5") stargazing case.

Remix of RonnyS's "Raspberry Pi Touch Display 2 Case" (Printables 1377047,
CC-BY), re-worked for the 5" panel and a Raspberry Pi 4 or Pi 5.

The case-bottom stacks onto the shell's back plate. The Pi is NOT carried by
the case: the display's built-in 15.9mm standoffs (58 x 49) carry it, via
M2.5 6+6 male-female extenders that rise through the central bay and relay
the mount plane ~3.5mm above this part's plate. Structure (RonnyS style):
  - central open BAY: extenders, Pi underside, DSI ribbon fold and JST
    jumper all live here; no pass-through holes needed
  - perimeter WALL around the bay. On the -Y edge one gap spans the whole
    power/HDMI group. On the +X edge the wall is NOT one gap: a continuous
    SILL runs under the connectors and full-height DIVIDERS stand between
    them, so each connector gets its own opening. RonnyS does the same with
    the sill (his +X wall stops at z 9.1 against a 12.4 wall top) though not
    with the dividers.
    The lid seats on this wall and continues its profile upward; there are
    no lid towers - the lid is retained by M2.5 male-female standoffs that
    screw into the extenders through the Pi's own mounting holes. Because
    that screw chain is long and compliant (extender -> Pi -> standoff), it
    locates the lid poorly, so four SPIGOTS on the wall top drop into blind
    sockets in the lid skirt and take the sideways load instead. RonnyS has
    no such feature: his lid bolts into towers rising from his own plate,
    which is short and stiff enough not to need one.
  - 103.7 x 51 clearance holes for the M2.5 case screws
    (here -> shell back -> display screw bosses). Those same four screws also
    bolt the two desk stands to the X flanges, so the flanges carry no
    features at all - the stands simply lie on the bare rear face. Nothing
    may protrude from the plate's FRONT face, which clamps against the
    shell's back plate.

Landscape: X = long axis, Y = short axis, centred on origin to match the
shell. Pi long edge along X; USB/Ethernet faces +X, power/HDMI faces -Y,
DSI faces -X. Local Z equals assembly Z (plate 0..2.5, wall top 10.5).

Print orientation: plate flat on the bed, wall up. No supports.
"""

import sys

import cadquery as cq
import pi_models as pm

VERSION = "0.18.0"

# Which board this plate is cut for; "python case_bottom.py pi5" for the other.
# The board outline and the 58 x 49 mount pattern are identical, so only the
# port openings differ.
PI_MODEL = sys.argv[1] if len(sys.argv) > 1 else "pi4"
assert PI_MODEL in pm.PI_MODELS, f"unknown model {PI_MODEL}"

# ============================================================
# PARAMETERS - all mm.
# ============================================================
# --- Display's built-in Pi standoffs (the 15.9mm towers on the panel rear) ---
# The M2.5 6+6 extenders screw into these; the Pi then bolts to the extenders.
# NOT the 103.7 x 51 screw bosses below - those are a separate, lower pattern.
ext_span_x = 58.0     # pattern along the landscape long axis
ext_span_y = 49.0     # pattern along the landscape short axis
# MEASURED on the panel: along the long axis the standoffs are 34mm from the
# DSI-end edge and 51.5mm from the other (34 + 58 + 51.5 = 143.5 ~ 143.4); along
# the short axis both are 21mm from the edge (21 + 49 + 21 = 91 ~ 91.46), i.e.
# centred. So the pattern sits 8.7mm toward the DSI end in X.
ext_off_x = -8.7      # (-143.4/2 + 34) + 29
ext_off_y = 0.0       # centred within measurement tolerance

# --- Raspberry Pi board (derived position, for clearance checks) ---
pi_w = pm.BOARD_W
pi_h = 2 * pm.BOARD_HY
pi_hole_inset = 3.5   # holes 3.5 from the DSI end and both long edges

# --- Display mount (case screws) ---
disp_span_x = 103.7
disp_span_y = 51.0
disp_hole_d = 2.9     # M2.5 clearance

# --- Base plate ---
base_t = 2.5
base_r = 3.0
# The X flanges reach past the lid skirt so the desk stands have somewhere to
# sit; stand.py's strap spans case X 49.0..63.0 and takes half_x as its
# outboard edge. This was briefly 64.5, to push the old snap-on legs clear of
# the case-screw heads they used to straddle; the bolt-on stands sit ON those
# screws, so it is back to 63.0 and plates printed before the stand work fit.
half_x = 63.0
half_y = 38.0

# --- Central bay ---
bay_x0 = -46.0        # ~5mm past the Pi's DSI edge so the ribbon can wrap
bay_x1 = 44.0         # just past the Pi's port end (43.8)
bay_hy = 29.5         # half-height; Pi long edges (+-28) overhang slightly
bay_r = 3.0

# --- Perimeter wall ---
wall_t = 2.5
wall_h = 8.0          # clears the Pi plane (~3.5 above plate) + lid seat

# --- Port openings (all derived from the measured table in pi_models.py) ---
port_clear = 0.6      # each side of a connector, in the wall plane
sill_clear = 0.35     # +X sill to the lowest connector underside. Fine here
                      # because nothing passes over that sill: the connectors
                      # protrude past the wall's outer face, so the plug body
                      # never reaches it.
bot_sill_clear = 2.0  # -Y sill to the lowest socket underside. Deliberately
                      # much larger: these connectors stop at the wall's inner
                      # face, so a PLUG passes over this sill, and an overmould
                      # hangs below its socket by an amount nothing here
                      # measures. This is the least certain number in the part.
                      # One flat sill spans the whole opening, so this is the
                      # margin under the LOWEST socket - the USB-C on both
                      # boards - and every other port gets at least as much.
port_margin = 1.7     # around the whole -Y port group
min_divider = 1.8     # thinnest acceptable divider or end wall

# --- Lid locating spigots ---
# Pads bulge OUTWARD on the +/-Y walls, into the 6mm of bare flange between
# the wall (32.0) and the plate edge (38.0). They cannot go on -X (the stand
# strap starts at x 49.0, only 0.5mm clear of the wall) or on +X (ports).
spigot_x = (-40.0, 31.0)
spigot_d = 3.0
spigot_h = 3.0
pad_len = 7.0         # along X
pad_t = 6.5           # total wall thickness at a pad, replacing wall_t. Sized
                      # by the LID's socket, not this pin: 6.5 leaves 1.5mm
                      # either side of a 3.5 socket, and that wall is what
                      # takes the sideways load.
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

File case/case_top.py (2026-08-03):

"""Ventilated lid (case-top) for the Touch Display 2 (5") stargazing case.

Remix of RonnyS's "Raspberry Pi Touch Display 2 Case" (Printables 1377047,
CC-BY), re-worked for the 5" panel and a Raspberry Pi 4 or Pi 5.

The lid continues the case-bottom's wall profile upward: its skirt has the same
footprint as that wall and seats on top of it, so the two form one continuous
side. It is retained by four M2.5 screws that pass through the top face into
M2.5 male-female standoffs, which in turn screw into the extenders through the
Pi's own mounting holes (58 x 49). There are therefore NO lid towers and NO
heat-set inserts - one screw chain does the whole stack.

That chain is long and compliant, though (extender -> Pi -> standoff), so the
screws alone locate the lid poorly and it could slide sideways on its seat.
Four blind SOCKETS in the skirt take spigots standing on the case-bottom's wall
and carry the sideways load instead. The pads that house them are the only
places the footprint departs from the wall below.

Port apertures are the upper half of an opening whose lower half is the gap in
the case-bottom's wall; both halves are derived from pi_models.py so they
cannot drift apart. On the +X face there is one window per connector rather
than a single span, matching the dividers in the wall below.

MODELLED IN ASSEMBLY COORDINATES (Z = 0 at the shell back plate's outer face,
+Z rearward) and flipped to print orientation only at export - the outer face
ends up on the bed. Modelling in print orientation previously meant mirroring
every side feature by hand, which is how the port apertures ended up on the
wrong side once already.

Stack: Pi PCB top 7.4 | standoff 20 -> lid inner face 27.4 | outer face 30.4
"""

import sys

import cadquery as cq
import pi_models as pm

VERSION = "0.8.0"

# Which board this lid is cut for; "python case_top.py pi5" for the other.
PI_MODEL = sys.argv[1] if len(sys.argv) > 1 else "pi4"
assert PI_MODEL in pm.PI_MODELS, f"unknown model {PI_MODEL}"

# ============================================================
# PARAMETERS - all mm, assembly coordinates.
# ============================================================
# --- Footprint: MUST match case_bottom's wall (it seats on it) ---
out_x0, out_x1 = -48.5, 46.5    # = case_bottom wall_x0 / wall_x1
out_hy = 32.0                   # = case_bottom wall_hy
in_x0, in_x1 = -46.0, 44.0      # = case_bottom bay_x0 / bay_x1
in_hy = 29.5                    # = case_bottom bay_hy
out_r, in_r = 5.5, 3.0
wall_t = 2.5                    # = case_bottom wall_t

# --- Heights ---
z_skirt = 10.5        # case_bottom wall top - the lid seats here
standoff = 20.0       # M2.5 male-female standoff on top of the Pi
pi_top = 7.4
top_t = 3.0           # top face thickness (thick enough to counterbore)

# --- Lid screws -> standoffs (the Pi's own 58 x 49 pattern) ---
ext_span_x, ext_span_y = 58.0, 49.0
ext_off_x, ext_off_y = -8.7, 0.0    # measured; must match case_bottom
screw_d = 2.9         # M2.5 clearance
cbore_d = 5.2
cbore_depth = 1.5

# --- Port apertures (upper half; lower half is the case-bottom wall gap) ---
port_clear = 0.6      # each side of a connector, in the wall plane
port_clear_z = 0.8    # above a connector
port_margin = 1.7     # around the whole -Y port group  } must match
min_divider = 1.8     # thinnest acceptable divider     } case_bottom
# A window stops short of the roof to leave a lintel. Where that lintel would
# come out thinner than this, the window is taken all the way up instead - a
# 1.5mm lintel spanning a 16mm connector is worse than no lintel at all.
min_lintel = 2.0

# --- Lid locating spigots: sockets over case_bottom's pins ---
spigot_x = (-40.0, 31.0)        # must match case_bottom
spigot_d = 3.0
spigot_h = 3.0
spigot_fit = 0.25               # radial clearance, pin to socket
pad_len = 7.0
pad_t = 6.5           # 1.5mm of wall either side of the socket

# --- Fan grille + optional 40x40x10 fan on the inner face ---
grille_hole_d = 4.0
grille_pitch = 6.0
grille_r = 17.0
fan_span = 32.0
fan_thick = 10.0
fan_screw_d = 3.4
fan_cbore_d = 6.5
fan_cbore_depth = 2.0

# --- Passive vents in the -X and +Y skirts ---
vent_w = 3.0
vent_z0, vent_z1 = 14.0, 25.0
vent_pitch = 8.0
vent_n = 5

# ============================================================
# DERIVED
# ============================================================
z_inner = pi_top + standoff          # 27.4
z_outer = z_inner + top_t            # 30.4
height = z_outer - z_skirt           # 19.9

ex, ey = ext_span_x / 2, ext_span_y / 2
screws = [(ext_off_x + sx * ex, ext_off_y + sy * ey)
          for sx in (1, -1) for sy in (1, -1)]

fh = fan_span / 2
fan_holes = [(fh, fh), (-fh, fh), (fh, -fh), (-fh, -fh)]

_keepout = fan_cbore_d / 2 + grille_hole_d / 2 + 0.8
grille_pts = []
n = int(grille_r // grille_pitch) + 1
for i in range(-n, n + 1):
    for j in range(-n, n + 1):
        gx, gy = i * grille_pitch, j * grille_pitch
        if (gx * gx + gy * gy) ** 0.5 > grille_r:
            continue
        if any(((gx - fx) ** 2 + (gy - fy) ** 2) ** 0.5 < _keepout
               for fx, fy in fan_holes):
            continue
        grille_pts.append((gx, gy))

vent_offs = [(i - (vent_n - 1) / 2) * vent_pitch for i in range(vent_n)]

# port windows: (y0, y1, top) per +X connector
side_ports = pm.side_ports(PI_MODEL)
windows = []
for (_name, y0, y1, _z0, z1, _reach, _under) in side_ports:
    top = z1 + port_clear_z
    if top > z_inner - min_lintel:
        top = z_inner
    windows.append((y0 - port_clear, y1 + port_clear, top))

# material left standing between the windows (dividers) and at each end
edges = [-in_hy] + [v for w in windows for v in w[:2]] + [in_hy]
side_solids = [(edges[i], edges[i + 1]) for i in range(0, len(edges), 2)]

bot_x0, bot_x1 = pm.bottom_span(PI_MODEL)
pwr_x0 = bot_x0 - port_margin
pwr_x1 = bot_x1 + port_margin
pwr_z1 = max(e[4] for e in pm.bottom_external(PI_MODEL)) + port_clear_z

socket_d = spigot_d + 2 * spigot_fit
socket_depth = spigot_h + 0.6
pad_cy = in_hy + pad_t / 2
sockets = [(px, sy * pad_cy) for px in spigot_x for sy in (1, -1)]
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

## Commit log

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2026-06-14 Add one-time setup.sh; fix deploy.ps1 reserved var and sudo scope
    - setup.sh installs fonts + spidev/rpi.gpio system packages and writes
    a scoped sudoers rule so deploy.ps1 can manage systemd units without
    a password on subsequent deploys
    - Rename $Host -> $PiHost (PowerShell reserved variable)
    - Remove apt-get from deploy.ps1 (now in setup.sh)
2026-06-14 Fix display init and config deploy
    - Use explicit Inky(resolution=(600,400)) instead of auto() — auto()
    requires EEPROM I2C detection which fails when display is not yet
    connected or I2C isn't initialised
    - deploy.ps1 now always copies local config.toml to Pi so the real
    HA token is deployed (previously only copied example on first run)
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2026-06-14 Fix canvas and init resolution: 640x400 not 600x400
    Pimoroni inky 2.4.0 driver defines the 4" Impression as 640x400
    (_RESOLUTION_4_INCH). The product page says 600x400 but the actual
    driver resolution is 640x400.
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2026-06-27 Add 3D-printable desktop stand case for the Inky Impression 4"
    Frame + slot-in kickstand leg, designed in Fusion 360 around the
    real Inky PCB dimensions, mounting holes, and Pi Zero 2W clearance.
    Includes the editable .f3d source and ready-to-print STLs.
    [inky_case.f3d, inky_case_frame.stl, inky_case_leg.stl]
2026-06-27 Redesign case stand as a 4-corner screwed back panel + riser/foot
    Replaces the friction-fit slot-in leg (toppled too easily, tabs
    overhung the foot) with a full back panel screwed to the frame at
    all 4 corners. Frame enlarged to fit corner mounting posts outside
    the PCB footprint; PCB pocket given proper clearance (was a 0mm
    interference fit). Panel includes 4 retention posts reaching the
    PCB's back face to hold the board against the front window, and a
    centered foot wedge for a shallower 13deg desk lean (was 30deg).
    [inky_case.f3d, inky_case_frame.stl, inky_case_leg.stl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]
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2026-06-30 Migrate case from Fusion 360 to parametric CadQuery; drop decorations
    Replace the Fusion-authored case (inky_case.f3d and its exported STLs)
    with parametric CadQuery scripts as the single source of truth.
    - case_frame_v2.py: faithful port of the frame (Body1), geometry
    reverse-engineered from the original STL by cross-sectioning. Outer
    117.6x89.5x16mm, 2mm bezel, 86x54mm display window, 97.6x69.5mm PCB
    pocket, cable slot, 4 corner M2.5 pilot holes. Window shifted down
    0.5mm (centre Y +2.15) so the top bezel grows and the notch-side
    bezel shrinks by 0.5mm.
    - case_riser_v2.*: the previously-rebuilt CadQuery riser/back panel
    (now committed alongside the frame so the pair stays cohe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
    [case_frame_v2.stl, case_riser_v2.3mf, case_riser_v2.stl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]
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2026-07-02 Add addressable LED bezel ring, diffusers and riser vents
    Extend the case (v3.0) with an optional WS2812B LED bezel ring:
    - Grow the frame +4mm/side (117.6x89.5 -> 125.6x97.5) so the bezel band
    can host a 10mm strip channel; window/pocket/screws are unchanged, so
    the validated PCB/display fit and the frame<->riser mate are preserved.
    - 20 LEDs (6/6/4/4) light a continuous slot per side behind white
    diffuser inserts (case_diffusers_v1) for an even glow rather than
    discrete dots. Snap tabs retain the strip; corners stay solid for the
    screws, with jumper-wire notches routed clear of the pilots.
    - Add a 45-hole vent grid over the Pi in the riser back panel.
    - Document strip sourcing,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
    [case_diffusers_v1.stl, case_frame_v2.stl, case_riser_v2.3mf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]
2026-07-02 Route LED corner jumpers through strip-level tunnels
    Replace the back-face L-grooves with straight tunnels through each solid
    corner at strip level (Z bezel_t..bezel_t+led_ch_clear_z). The jumper wire
    between segments now stays in the strips' plane instead of bending to the
    rear and back, which the slicer showed as an awkward multi-bend path. The
    front-level tunnels also clear the corner screw pilots automatically (those
    sit at the back, Z11..16), so no outboard detour is needed.
    [case_frame_v2.stl]
2026-07-02 Print diffuser into frame via MMU instead of a separate insert
    Replace the separate friction-fit diffuser strip with a translucent window
    printed into the frame's slots as a second MMU material. The frame script now
    exports the frame plus an aligned case_frame_v2_windows.stl (0.8mm windows) to
    co-print in the translucent extruder; case_diffusers_v1 is dropped.
    Within the channel band the front is thickened to slot_front_t (diff_t 0.8 +
    led_gap 3.0 = 3.8mm): the diffuser window at the face, then a 3mm air gap, then
    the strip - which now seats against that shoulder for a positive front-stop 3mm
    behind the diffuser, so the light spreads and there are no hotspots. Fusing the
    diffuser in also re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
    [case_diffusers_v1.stl, case_frame_v2.stl, case_frame_v2_windows.stl]
2026-07-02 Add denser LED retention tabs with more projection
    Drive tab count off a target spacing (tab_spacing=22mm) instead of a fixed 3
    per side, giving ~6 tabs top/bottom and ~4 per side (was ~48mm gaps, now
    ~19-21mm). Bump tab_proj 1.5 -> 1.8mm (1.5mm edge-catch). Stops a flexible
    strip bowing backward out of the channel between tabs; the 0.3mm depth slop
    is kept so insertion stays easy.
    [case_frame_v2.stl]
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2026-07-02 Rewrite LED power wiring around a Wago junction off the supply
    Replace the "tap the Pi 5V pad" method with two Wago 221s spurring 5V/GND
    off the supply, so LED current never flows through the Pi and only the
    GPIO18 data lead touches the header. Cut the Stontronics plug, meter
    polarity, feed the Pi back via a micro-USB pigtail (keeps its polyfuse).
    Note 24 AWG into the Wago (26 AWG is at the connector's clamp floor).
2026-07-02 Move LED data to GPIO19 (pin 35) for an easier solder joint
    The rpi_ws281x driver isn't limited to GPIO18 - PWM1 is available on
    GPIO19 (pin 35), which is unused by the Inky and has two free neighbours
    (pins 33/37), so a solder slip there is harmless (vs pin 12, whose
    neighbour is GND). Update the wiring, gauge table, and rpi_ws281x skeleton
    (LED_PIN=19, LED_CHANNEL=1).
2026-07-02 Make the diffuser window a continuous filleted ring
    Replace the four separate straight windows with one filleted-rectangle
    window ring round the whole frame. The straight sides still glow (LED
    channels behind); the corners are a decorative translucent inlay - a shallow
    0.8mm front recess with solid frame behind (no channel/clearance) - to
    soften the frame's corners. Corner fillet = corner_r so the ring echoes the
    frame's outer corners.
    [case_frame_v2.stl, case_frame_v2_windows.stl]
2026-07-03 Open LED corner trenches to the back for pre-soldered fitting
    The v3.0 corner wire passages were enclosed diagonal tunnels bored across
    each corner at strip level. They cleared the corner screw only by running in
    front of it, but being closed on all sides a pre-soldered jumper could not be
    pulled through - forcing awkward solder-in-place with over-long leads.
    Replace them with open-to-back L-shaped trenches that route each jumper round
    the outboard side of the corner screw, so the whole strip + corner-link loop
    solders first and lays straight in from the back. Front face, diffuser ring
    and screw bosses are untouched; clearance assertions guard the screw walls.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
    [case_frame_v2.stl]
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2026-07-03 Drop the unfittable corner snap tab at one end of each channel (v3.2)
    The tab nearest the corner at each channel's trailing end could not be used:
    once a strip segment is seated under the inner tabs it cannot flex enough to
    tuck under a tab right by the corner. Remove one end tab per channel in a
    180-deg-rotational pattern (top->left, right->top, bottom->right, left->bottom);
    the other end and all inner tabs keep theirs. If backward retention there ever
    matters, a push-fit clip behind the strip, held by the back panel, is the
    fallback.
    [case_frame_v3.stl]
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2026-07-29 Add generated exploded assembly diagram
    The reference model ships an assembly sheet and this remix had none, so the
    written steps in case/README.md had nothing to point at.
    Generated rather than drawn: assembly_diagram.py loads the four part STLs,
    applies the real assembly transforms, explodes them and renders an isometric
    view, so the diagram cannot drift from the geometry - re-run it after
    changing a part.
    Two details worth keeping:
    - Fastener centre-lines are sampled along the 3D segment and depth-tested
    against the render depth buffer, so they pass behind parts rather than
    painting over them. Without this a stand-screw path appeared to lie on
    the Pi it is actually 45mm below.
    -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
    [assembly_diagram.py]
2026-07-29 Fix port cut-outs and retain the lid on standoffs, not towers
    First full assembly found three faults, and one of them exposed a
    structural improvement worth taking.
    Faults:
    - The case-bottom -Y wall gap still spanned -27..26. When the measured
    standoff offset moved the Pi 8.7mm I updated the lid aperture to
    -36..18 and missed its other half, so the USB-C socket at x -30 sat
    behind solid wall. Both halves now match, with an assertion tying the
    gap to the real port positions so they cannot drift apart again.
    - The lid USB/Ethernet aperture topped out at Z 22.0 against connector
    cans reaching 23.4, clipping them. Now 25.0.
    - The lid skirt ended 5.5mm short of the case-bottom, leavin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
    [case_bottom.stl, case_top.stl]
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2026-07-29 Snap the stand legs on instead of screwing them
    The legs were held by two M2.5 self-tappers each. The lower of the two
    lands inside the leg's own lightening void, where the foot rib blocks a
    driver coming straight in from behind - so it could not be reached once
    the leg was offered up. Self-tapping into a 2.5mm plate was also the
    weakest joint in the case.
    Replaced with a screwless cleat. Each flange grows two half-dovetail ribs
    and a detent bump on its REAR face (nothing may protrude from the front,
    which clamps against the shell). The leg slides UP to engage, which is the
    direction the case's weight already drives it, so load seats the joint
    instead of working it loose; the two dovetails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
    [case_bottom.stl, stand.stl, stand_15.stl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]
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2026-07-30 Trap the detent bump so the joint actually locates
    Printed and tested: the leg slid on with no retention at all, and the
    bump engaged nothing. Both were design errors, not print faults.
    At the seated position NOTHING touched. The relief was 4.0mm long for a
    2.4mm bump, so the bump floated with 1.6mm of dead space; the tongue tip
    sat 0.2mm clear; the dovetails had 0.25mm of slant clearance. Every
    interface had a gap at rest. The bump was also a symmetric 45 degree
    triangle whose base sat level with the tongue's tip, so first contact was
    at zero engagement depth - the 16N figure assumed full deflection at
    first contact, which the geometry never delivered.
    The bump is now the positive locator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
    [case_bottom.stl, stand_15.stl, stand_20.stl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]
2026-07-30 Let the dovetail taper clamp: it is the retention, not the detent
    Third printed version still had no tension: the bump sat in its notch with
    the tongue unsprung. That is what the design specified - a detent snaps
    down and relaxes - so the mechanism was wrong, not the dimensions.
    The taper was always self-clamping and I had engineered it out. Each rib's
    slant leans toward -Y as it rises and the leg's lip bears on it from
    below, so pushing the leg UP drives the lip along the slant and the
    reaction pulls the leg ONTO the flange. Push harder, grip harder, and the
    resulting friction resists sliding back. A wedge is also the one feature
    here immune to print tolerance: whatever slack the printer l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
    [stand_15.stl, stand_20.stl, stand_30.stl]
2026-07-30 Spring the tongue permanently: preload, not a latch
    Fourth printed version still had no tension, including at a nominal
    -0.05mm interference on the dovetail. The mechanism was wrong: I had been
    building a LATCH, which by definition relaxes once seated, then tuning
    0.05mm clearances to try to generate grip. FDM holds about +-0.15mm on
    these features - three times that entire adjustment range - so no value
    was ever going to work reliably.
    The user's reading of the design is the better one and is what this
    implements: keep the bump under the tongue AT ALL TIMES, including fully
    seated, so the tongue stays deflected by the bump's full 1.5mm. It then
    pushes the leg AWAY from the flange, pressing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
    [stand_15.stl, stand_20.stl, stand_30.stl]
2026-07-30 Flatten the retaining ledge so the spring stops ejecting the leg
    Tested on the printed v0.6.0: "the tension just pushes the dovetails
    open not closed". Correct, and it is quantifiable. The undercut sat at
    60 degrees from horizontal, so the lip bearing on it turned the tongue's
    uplift F into 1.75F along the slide against only 0.30F of friction - the
    spring drove the leg out of engagement. Every version since the first has
    failed on some version of this: I checked the clamping component of that
    contact force and never the component along the slide.
    Self-locking needs sin(ledge angle) < mu. The undercut is now a 1.0mm
    ledge at 10 degrees from horizontal: 0.18F of ejection against 0.30F of
    fric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
    [case_bottom.stl, stand_15.stl, stand_20.stl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]
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2026-07-30 Bolt the stands on with the case screws instead of snapping them
    Seven snap-on iterations failed because every one of them relied on a
    compliant feature holding a clearance an FDM printer cannot hold. This
    drops compliance entirely and returns to the reference architecture: a
    flat counterbored strap sharing that side's two M2.5 case screws.
    The shape is an L - strap plus a strut lying in the desk plane - with no
    diagonal brace, because a brace is exactly what crossed the Pi's port
    band and sank the previous side-flange leg. Measuring the reference Pi
    model showed the +X connector shells start at Z 6.65, 0.75mm BELOW the
    PCB top face the stack-up implies, so the usable band under them is
    4.1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
    [case_bottom.stl, stand_15.stl, stand_20.stl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]
2026-07-30 Put half_x back to 63 so plates printed before the stands still fit
    half_x was only widened to 64.5 to push the old snap-on legs clear of the
    case-screw heads they straddled. The bolt-on stands sit ON those screws,
    so the reason is gone, and reverting it means the case_bottom printed at
    v0.9.0 needs no reprint - the strap now ends exactly at the plate edge
    instead of overhanging it by 1.5mm.
    Strap 15.5 -> 14.0mm wide. Bending stiffness scales with width and the
    part had a safety factor over 10, so this is immaterial; the Ø5.4
    counterbores still sit well inside.
    Interference re-checked against a rebuild of the v0.9.0 plate as well as
    the current one: zero against both, and against case_top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
    [case_bottom.stl, stand_15.stl, stand_20.stl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]
2026-07-30 Put the stand screw holes on the screws, and hand the two parts
    The bores were placed at the strap's mid-width instead of on the screw
    axis, so the holes came out 4.15mm outboard of the case screws. Reaching
    a screw then meant sliding the leg 4.15mm inboard, which drove its edge
    into the -X perimeter wall - reported from a test fit as "the other leg
    is too wide", 7mm edge-to-hole against the 5mm the case allows. The +X
    leg escaped it only because that wall is cut away across the port gap,
    which is why one side fitted and the other did not.
    The hole offset is now derived from disp_span_x and asserted in case
    coordinates, which is where the error was invisible in leg coordinates.
    Two consequ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
    [stand_15.stl, stand_15_dsi.stl, stand_15_usb.stl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]
2026-07-30 Step the strut down over its outer half, like the strap
    The strut was a constant 9mm bar for its whole 45mm, but its bending
    moment is largest where it meets the strap and zero at the tip, so the
    outer material carried nothing. It now steps to 4.5mm past 20mm along the
    desk, using the same 45 deg chamfer and the same 2:1 ratio as the strap's
    own step, so the two transitions mirror each other.
    Thinning also pulls the strut's inner edge away from the Pi's plug band,
    which was the binding constraint on the 30 deg variant: its clearance
    goes 2.89 -> 4.90mm, so all three angles are now limited by the strap
    step rather than the strut.
    7.1cm3 against 8.8, about 9g a side instead of 11.
    Co-Author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
    [stand_15_dsi.stl, stand_15_usb.stl, stand_20_dsi.stl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]
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2026-07-31 Add a Pi 5 variant, lid spigots and per-connector ports
    The lid could slide sideways on its seat: it is held only by screws into
    standoffs stacked on the Pi, and that chain is too compliant to locate it.
    Measuring RonnyS's reference showed it solves this by not having the problem -
    his lid bolts into towers rising from his own plate, and the seated joint is a
    plain butt with 0.00mm of overlap, so there was no register to copy. Four Ø3
    spigots on the wall top now drop into blind sockets in the lid skirt and take
    the side load, keeping the single screw chain and needing no extra fasteners.
    Port openings are now cut per connector rather than as one long slot, over a
    continuous sill - the sill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
    [case_bottom.stl, case_bottom_pi4.stl, case_bottom_pi5.stl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]
2026-07-31 Put a sill under the power/HDMI ports too
    That edge was left as one full-height span when the USB/Ethernet edge got its
    per-connector treatment, which was a scope gap rather than a decision.
    It gets the sill but still no dividers, and the asymmetry is real: on the
    USB/Ethernet edge the connectors protrude past the wall's outer face, so a plug
    never touches the case and the sockets alone set the spacing. Here they stop at
    the inner face, so the plug's overmould passes through the opening. The two
    micro-HDMI sockets are 13.5mm apart, already tight for two cables on a bare
    Pi 4, so anything between them would likely stop both going in.
    bot_sill_clear is 1.5mm rather than the 0.35mm used on th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
    [case_bottom_pi4.stl, case_bottom_pi5.stl, case_top_pi5.stl]
2026-07-31 Drop the power/HDMI sill a further 0.5mm
    bot_sill_clear 1.5 -> 2.0 at the user's request. The sill top goes to Z5.35 on
    a Pi 4 and 6.00 on a Pi 5, still leaving a 2.85mm sill on the shorter of the
    two.
    One flat sill spans the opening, so this margin is the one under the lowest
    socket - the USB-C on both boards, which hangs 0.65mm below everything else on
    a Pi 4. The micro-HDMIs and audio jack there now clear by 2.65mm.
    [case_bottom_pi4.stl, case_bottom_pi5.stl]
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2026-08-01 Lift the case 10mm so the power lead clears the desk
    The USB-C socket faces the desk and even a right-angle adaptor'"'"'s overmould was
    longer than the gap underneath. The stands now hold the case 10mm higher, on top
    of the 3mm that keeps it off its own corner, giving about 27mm under the socket
    at every lean angle.
    Lifting perpendicular to the desk buys lift/cos(tilt) along the plug axis, which
    is why all three angles converge on the same clearance - it cancels the penalty
    for leaning back, where the socket moves toward the desk rather than away.
    The front tipping margin improves rather than suffers, 12.0 to 15.7mm at 20deg:
    the strap lies on the tilted rear face, so extending it moves th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
    [stand_15_dsi.stl, stand_15_usb.stl, stand_20_dsi.stl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]
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2026-08-01 Lift the case 20mm so the official Pi power supply fits
    The 10mm lift cleared a right-angle adaptor on hardware but not the supplied
    Raspberry Pi PSU: its captive cable has very little flex, so it cannot turn
    tightly and needs roughly another 10mm before it will run flat.
    Sizing for the supplied PSU rather than for a right-angle lead is deliberate.
    Anyone printing this case most likely has one, and "the power supply in the box
    does not fit" is a poor thing to discover after a print. Room under the socket
    goes to about 38mm at every lean angle.
    Flags 30 degrees as the marginal option in the README. Raising the case moves
    the centre of mass back, so the rear tipping margin falls with lift -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
    [stand_15_dsi.stl, stand_15_usb.stl, stand_20_dsi.stl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]
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2026-08-03 Lift the case another 2mm and slot the stand screw holes
    Both come from the same test fit of the reprinted stands.
    The official Raspberry Pi PSU went in at a 20mm lift but only just - its
    captive cable is thick and will not turn tightly, so it was still working
    against the desk. 22mm is the fitted answer. 30 deg remains the tilt that
    limits any further lift: its rear tipping margin is down to 11.5mm.
    The screw through-holes now run out through the strap's inboard edge, the
    same way the counterbores already do, so a stand can be slid on and off
    with the case screws slackened rather than withdrawn - taking them out
    means holding display, shell and case-bottom together unaided. The mouths
    hav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
    [stand_15_dsi.stl, stand_15_usb.stl, stand_20_dsi.stl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]
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2026-08-05 Make the 10-inch starfield the real sky
    The stars behind the dashboard were 520 seeded random points. They are now
    8,355 catalogue stars to magnitude 6.5, plotted where they actually are for the
    site and the minute, so the field turns because the Earth does rather than
    because a drift constant says so.
    THE DIRECTION IS CONFIGURATION, NOT INFERENCE. The panel cannot know which way
    it faces, so [sky] camera_azimuth/camera_altitude/field_of_view choose where the
    window looks - due south by default, since that is where everything transits
    from the northern hemisphere.
    Catalogue: Yale Bright Star Catalogue via VizieR (CDS Strasbourg, already this
    project's imagery source), shipped in core/data/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
    [stars.tsv]
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2026-08-07 Add a desk stand for the 10.1-inch panel
    One printed part and two M2.5 screws, holding the panel at a 10 degree lean
    with the Pi left open on its back. The 10.1-inch panel needs no case - it
    mounts and cools its own board - so all that was missing was a way for it to
    stand on a desk.
    The bosses stand 3 mm proud of the back plate, so a part bolted flat against
    them touches nothing but two small annular faces. The front face is therefore
    stepped: pads on the boss plane, and a bearing face 3 mm proud of them that
    reaches the plate itself, placed ABOVE the bolt line because the centre of
    mass is above the bosses and the plate below them lifts away. Below the bolt
    line the face stays deliberatel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
    [stand10.stl]
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2026-08-10 Clip the power lead down the back of the 10.1 inch stand
    The lead leaves the Pi at the top of the panel and hangs out to the side and
    behind. Two collars on the back of the upright take it down to the desk.
    They are on a bolt column rather than the centre rib, and as far outboard on it
    as they fit without overhanging the edge, because the overmould and the lead's
    own stiffness need room to turn - the further out the run, the wider the radius
    it can take. The upper collar stops 10 mm short of the top for the same reason,
    which is a distance in the source rather than the position it produces.
    Each collar is a ring drawn in (X, t) and extruded along s, so it leans back
    with the upright and ad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
    [stand10.stl]
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
